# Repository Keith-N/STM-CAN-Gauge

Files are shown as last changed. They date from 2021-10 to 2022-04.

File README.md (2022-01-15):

# STM-CAN-Gauge

An STM32F042 based CAN gauge for use with rusEFI ECUs. <br/>
CAN is configured for 500k with a base ID of 512. <br/>
Input voltage tested at 5V and 12V. <br/>

Flash 'CAN Gauge.bin' through STM32CubeProgrammer using STLink and TC2030. <br/>

The only required connections for operation are supply voltage/ground and CAN High/Low. <br/>

GaugeC_Front
GaugeC_Back

Pinout from the back of connector.
Pinout

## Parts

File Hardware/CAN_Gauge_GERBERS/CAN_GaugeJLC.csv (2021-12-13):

Comment | Designator | Footprint | LCSC
120u | C11 | Capacitor_SMD:C_1206_3216Metric | C15008
2.2u | C16,C18 | Capacitor_SMD:C_0402_1005Metric | C170151
0.1u | C1,C3,C5,C13 | Capacitor_SMD:C_0402_1005Metric | C1525
1u | C2,C4,C14,C15,C17 | Capacitor_SMD:C_0402_1005Metric | C389008
10u | C9,C10 | Inductor_SMD:L_1206_3216Metric | C13585
LED | D1,D2,D3,D4,D5,D6,D7,D8,D9,D10,D11 | LED_SMD:LED_0603_1608Metric | C2286
1N5817 | D12 | Diode_SMD:D_SOD-123 | C727113
SS16HE3_B/I | D21 | Diode_SMD:D_SMA | C211772
SMBJ16CD-M3/H | D22 | Diode_SMD:D_SMB | C8830
MountingHole | H1,H2,H3,H4 | MountingHole:MountingHole_2mm
Conn_02x03_Odd_Even | J1 | Connector:Tag-Connect_TC2030-IDC-NL_2x03_P1.27mm_Vertical
Conn_01x08 | J2 | Connector_Molex:Molex_Micro-Fit_3.0_43045-0812_2x04_P3.00mm_Vertical
SolderJumper_2_Open | JP1,JP2,JP3 | Jumper:SolderJumper-2_P1.3mm_Open_Pad1.0x1.5mm
100uH | L1 | Inductor_SMD:L_0805_2012Metric | C68035
30 | L2 | Inductor_SMD:L_0402_1005Metric | C76886
10k | R1,R3,R10,R11,R12,R13,R14,R15,R24,R25,R26 | Resistor_SMD:R_0402_1005Metric | C25744
120 | R20 | Resistor_SMD:R_0402_1005Metric | C60310
1k | R2,R7,R8,R9,R16,R17,R18,R19,R21,R29,R30 | Resistor_SMD:R_0402_1005Metric | C11702
SW_Push | SW1 | Button_Switch_SMD:SW_Push_1P1T_NO_6x6mm_H9.5mm | C480275
TestPoint | TP1,TP2,TP3,TP4,TP5,TP6,TP7,TP8 | TestPoint:TestPoint_Pad_D1.0mm
STM32F042K6Tx | U1 | Package_QFP:LQFP-32_7x7mm_P0.8mm
SN65HVD230 | U2 | Package_SO:SOIC-8_3.9x4.9mm_P1.27mm | C12084
2594 | U3 | Package_SO:SOIC-8_3.9x4.9mm_P1.27mm | C316691
UG-2864HSWEG01 | U4 | custom:SSH1106_Bottom

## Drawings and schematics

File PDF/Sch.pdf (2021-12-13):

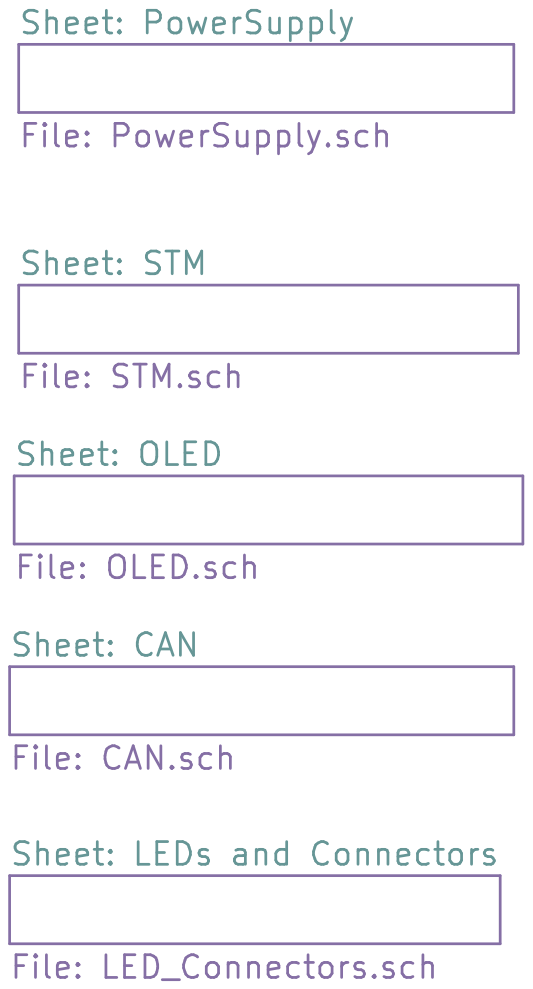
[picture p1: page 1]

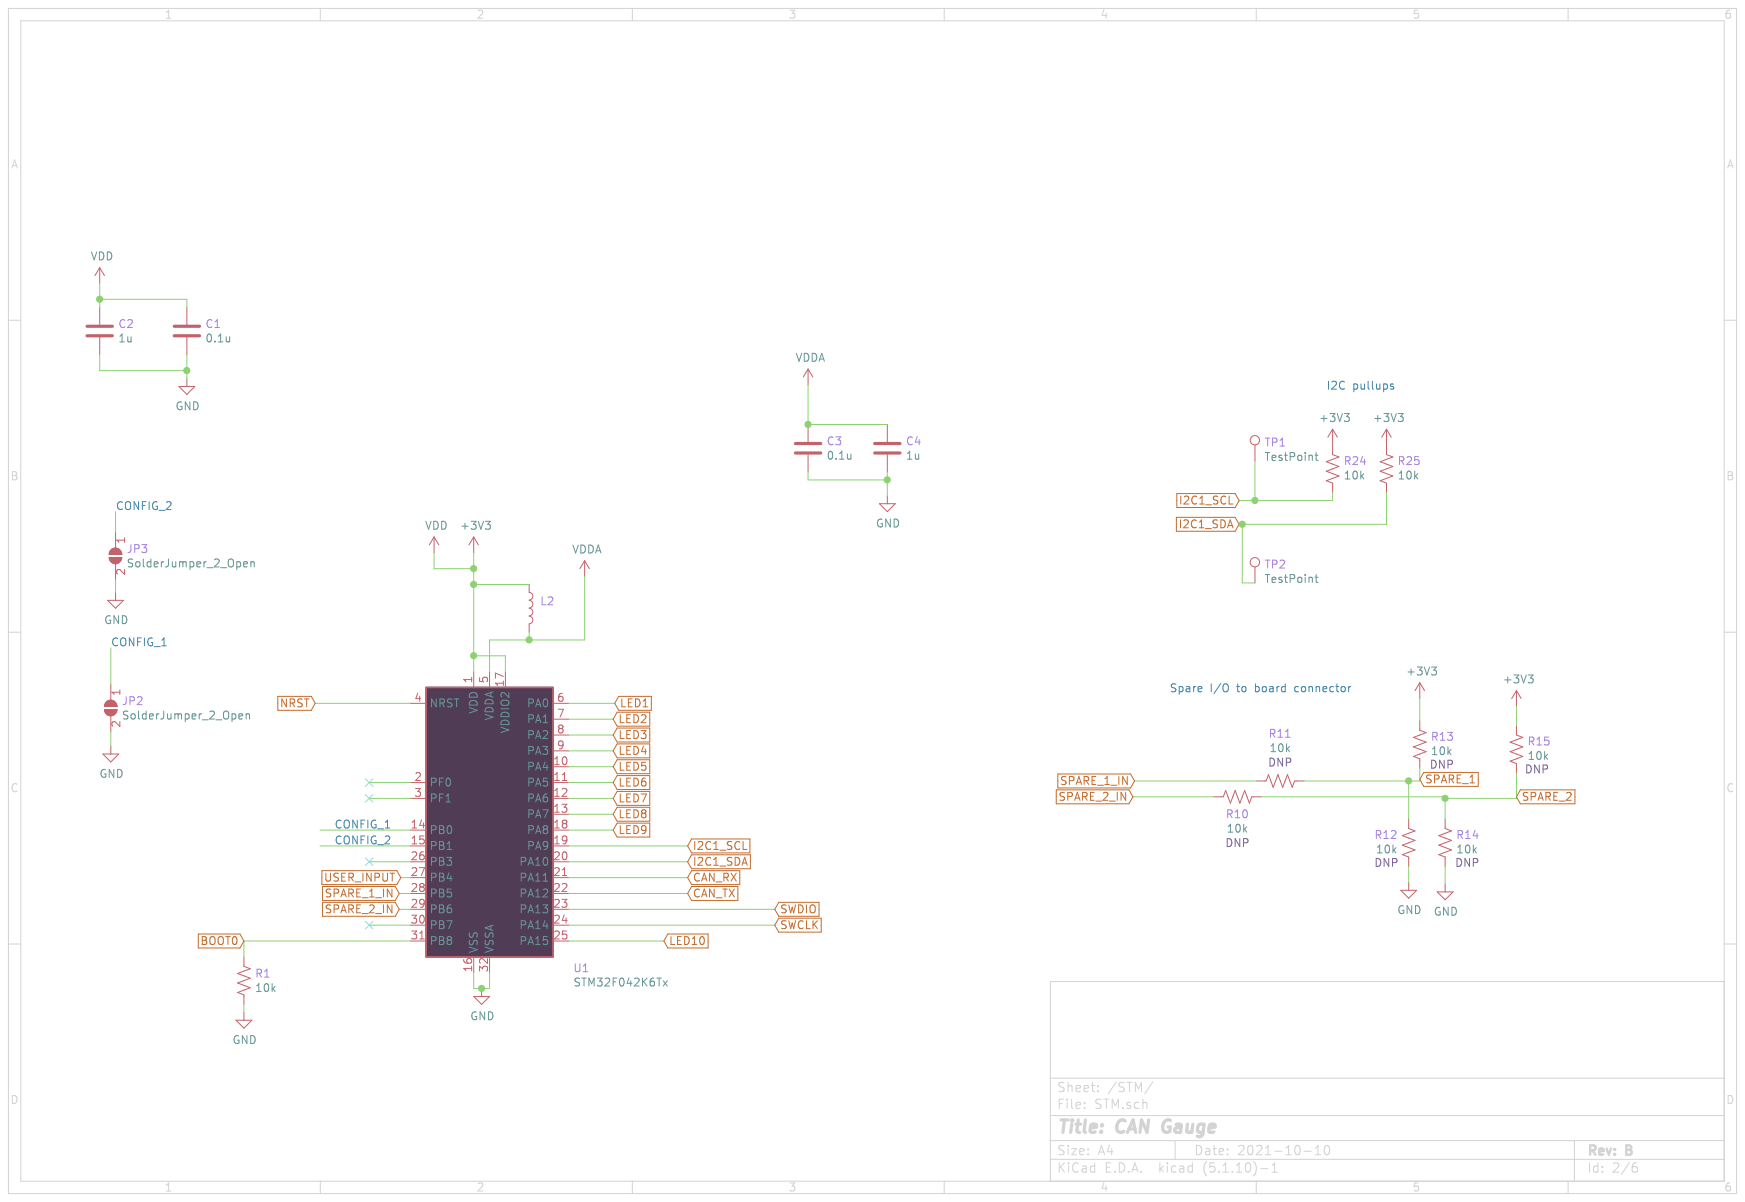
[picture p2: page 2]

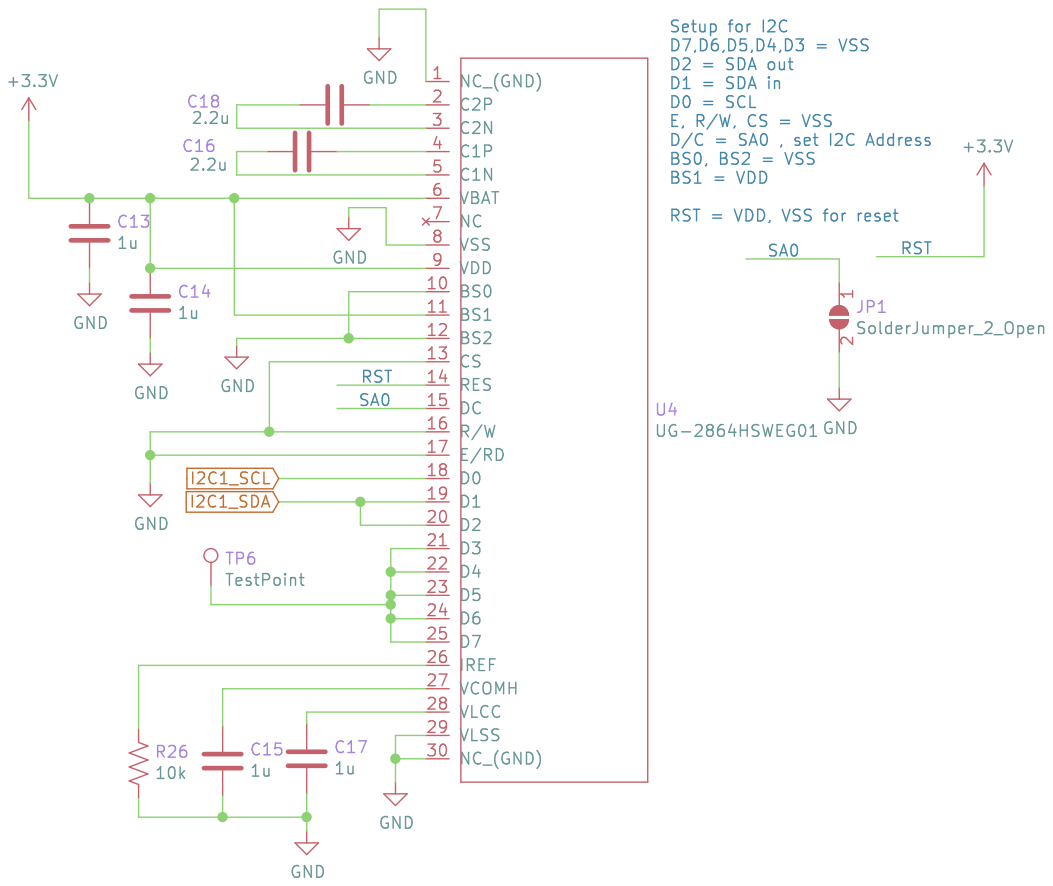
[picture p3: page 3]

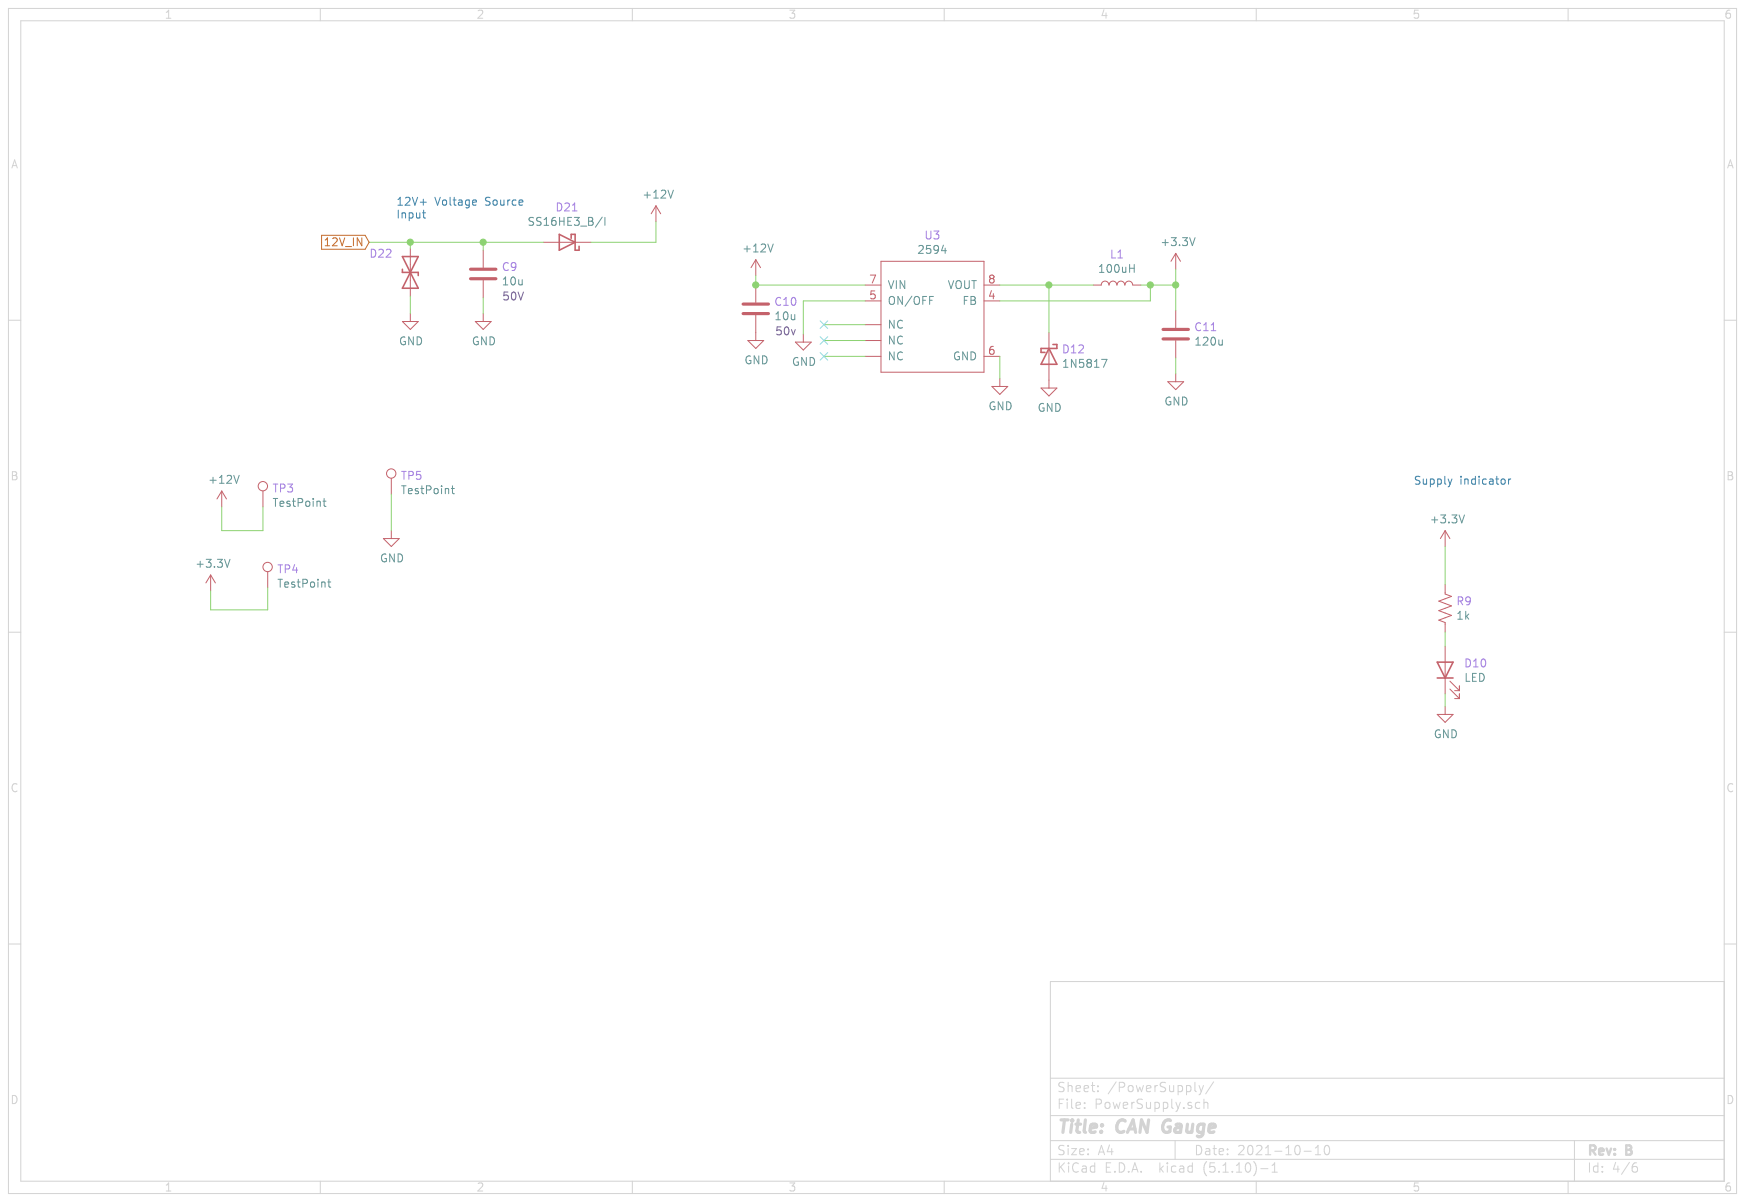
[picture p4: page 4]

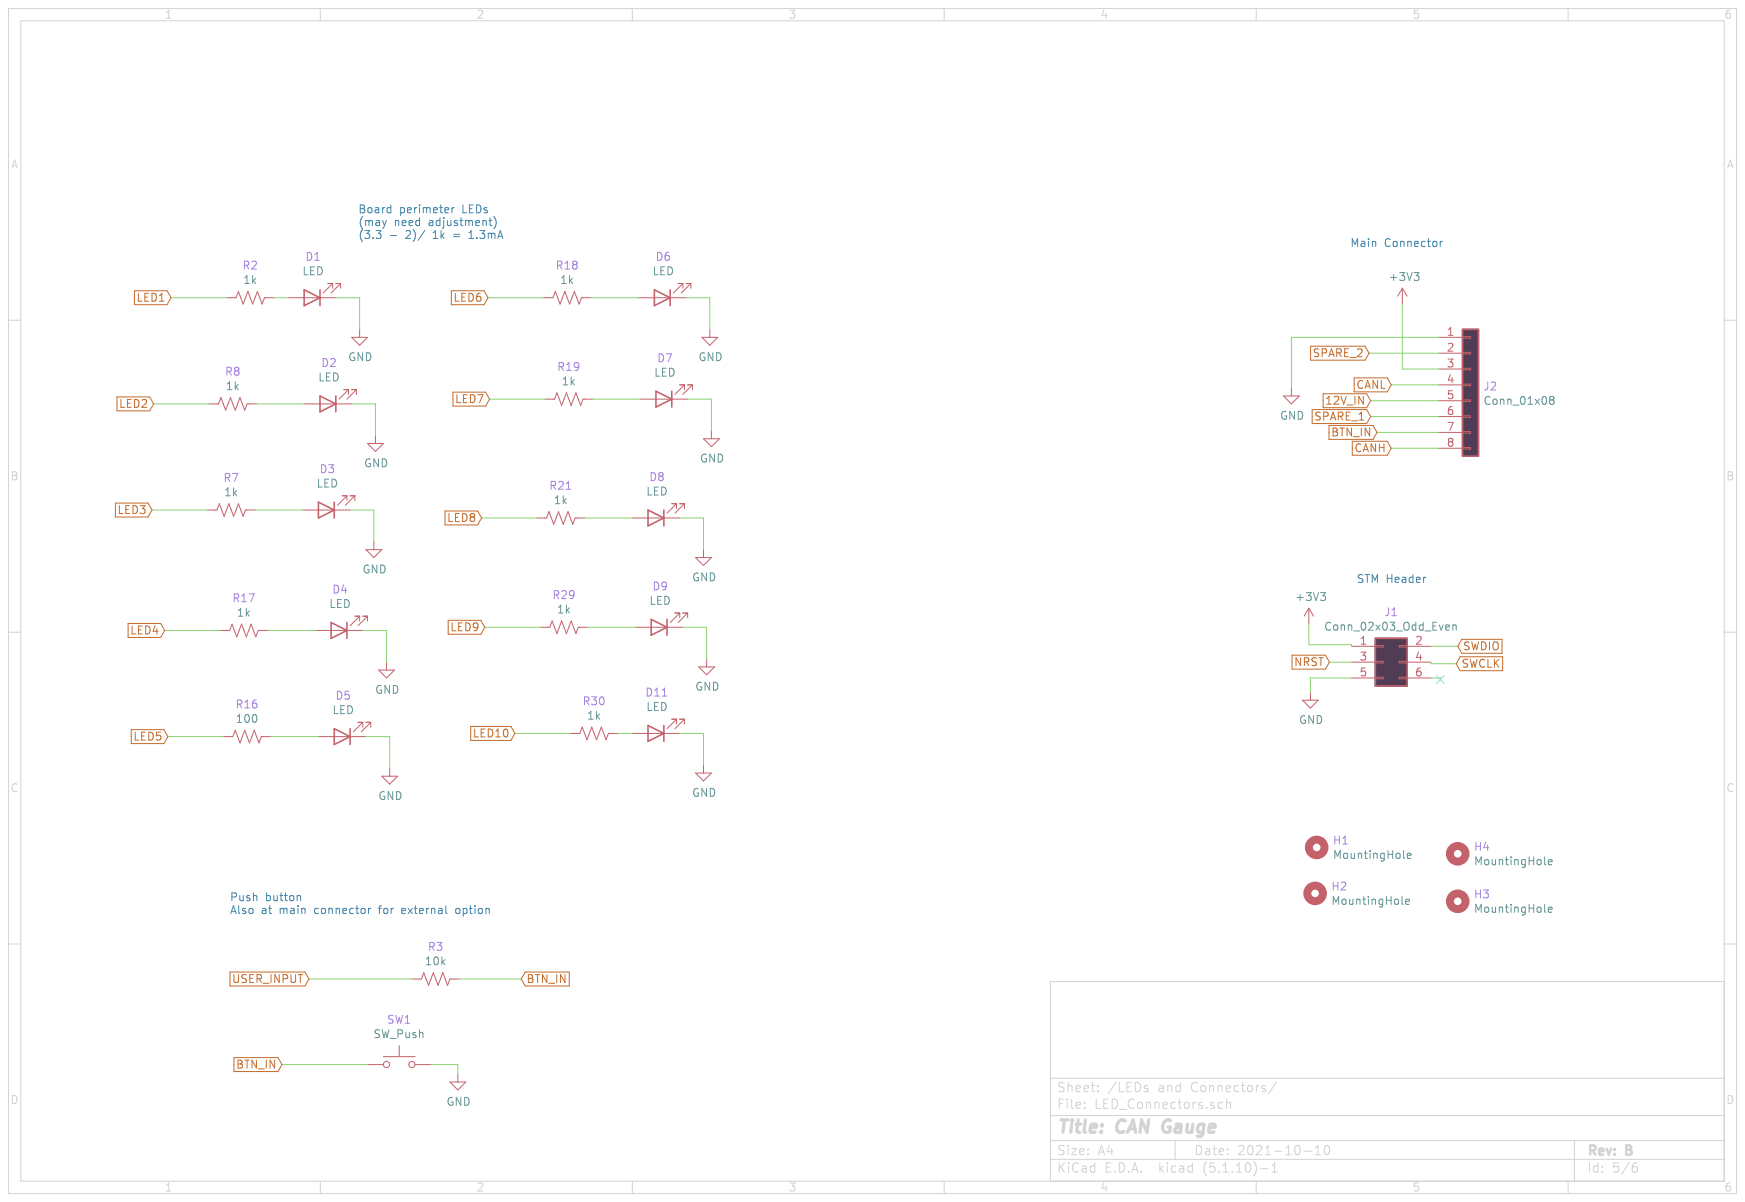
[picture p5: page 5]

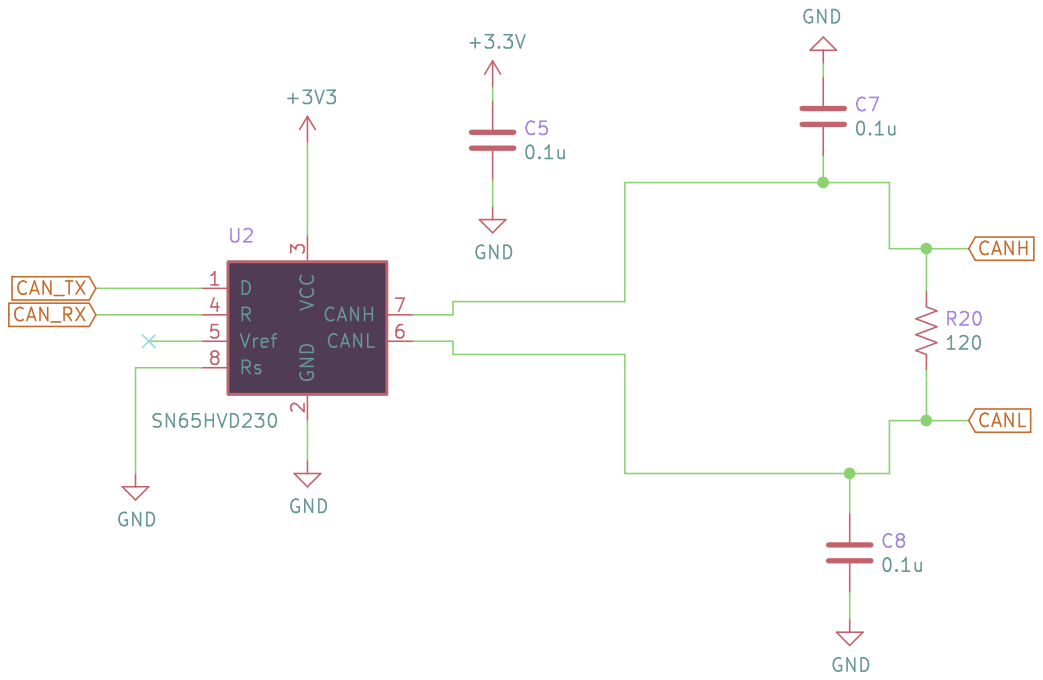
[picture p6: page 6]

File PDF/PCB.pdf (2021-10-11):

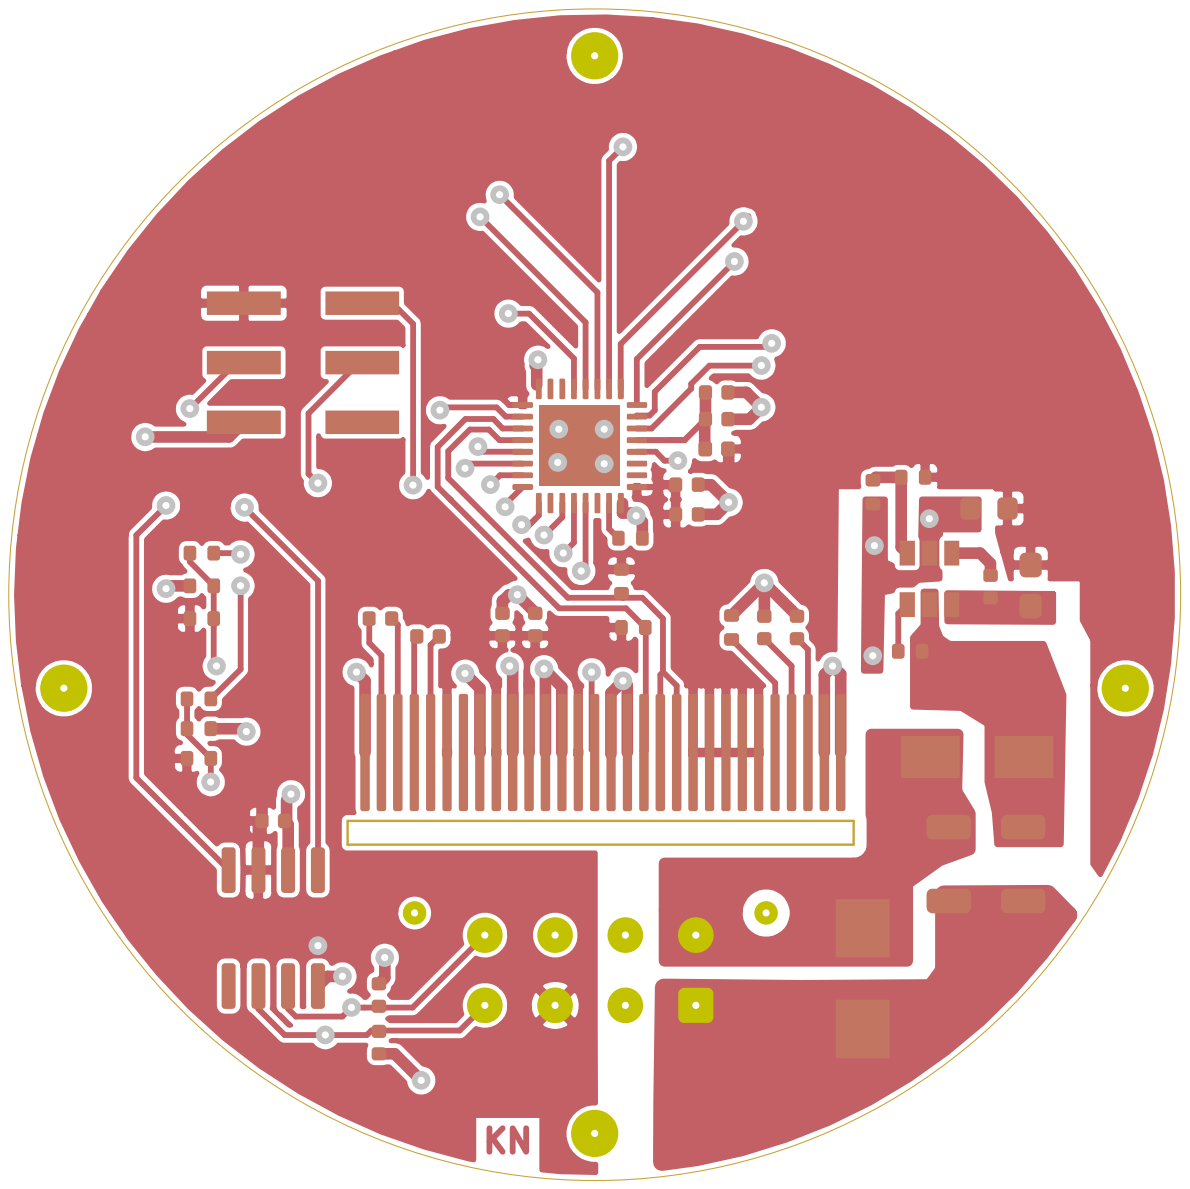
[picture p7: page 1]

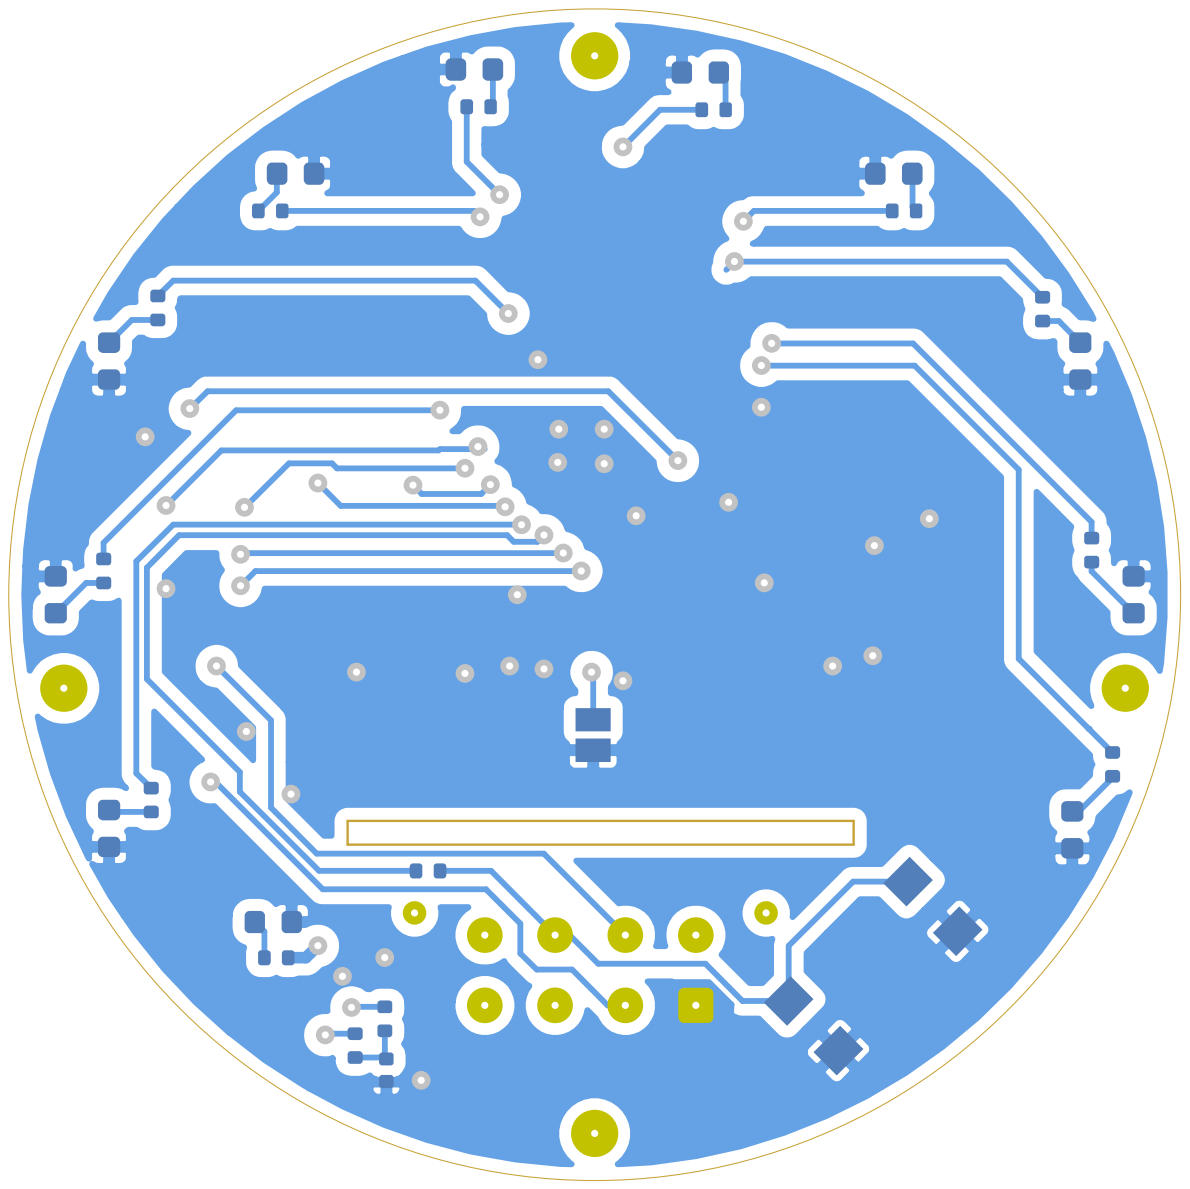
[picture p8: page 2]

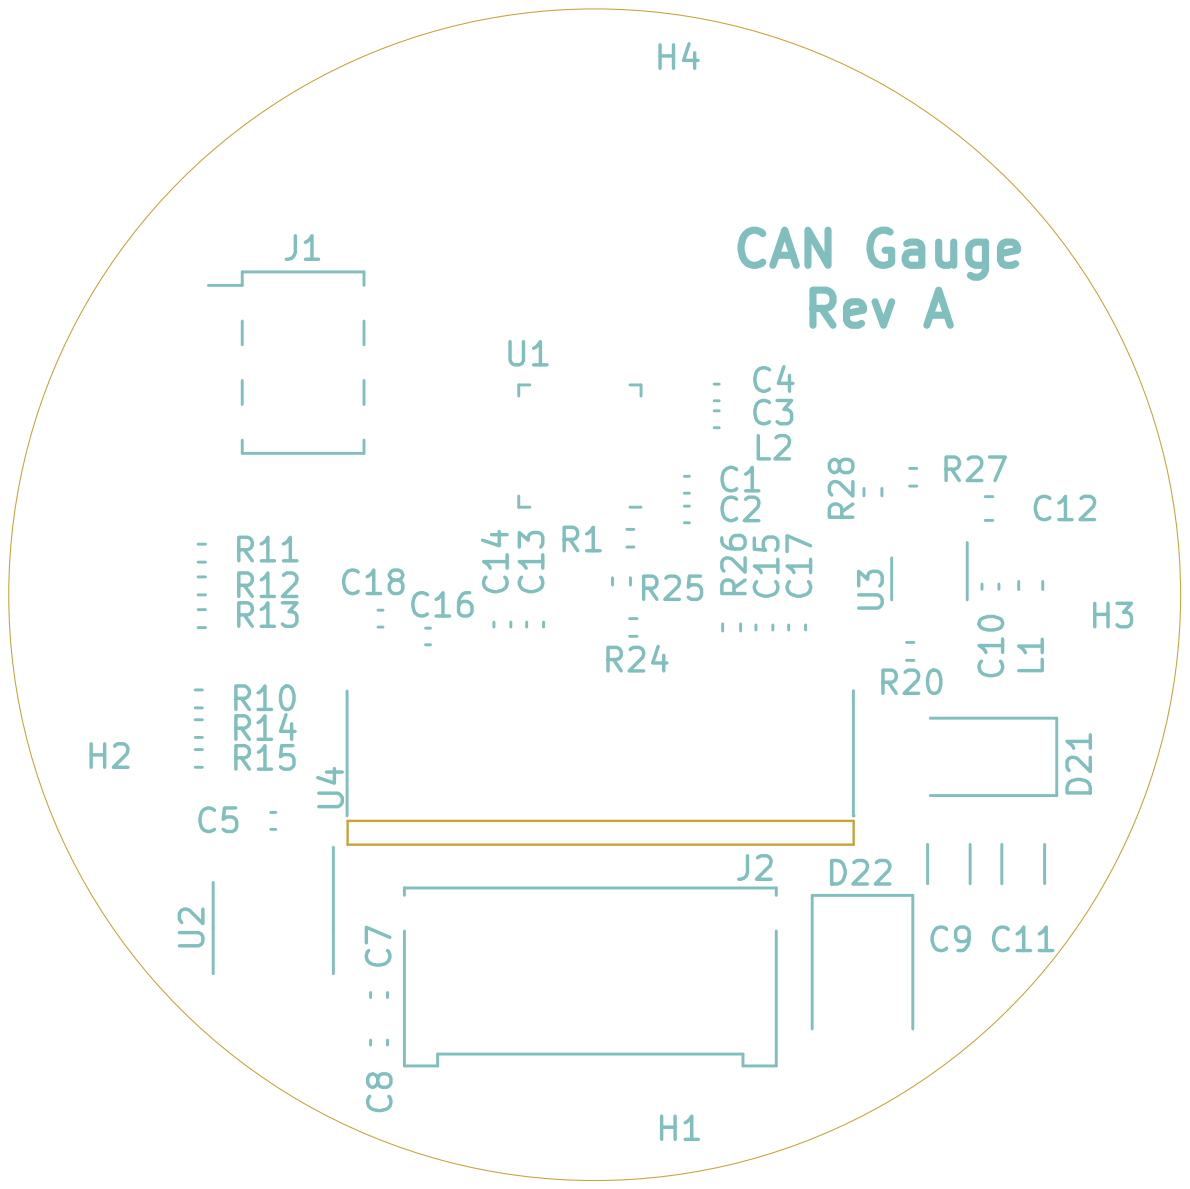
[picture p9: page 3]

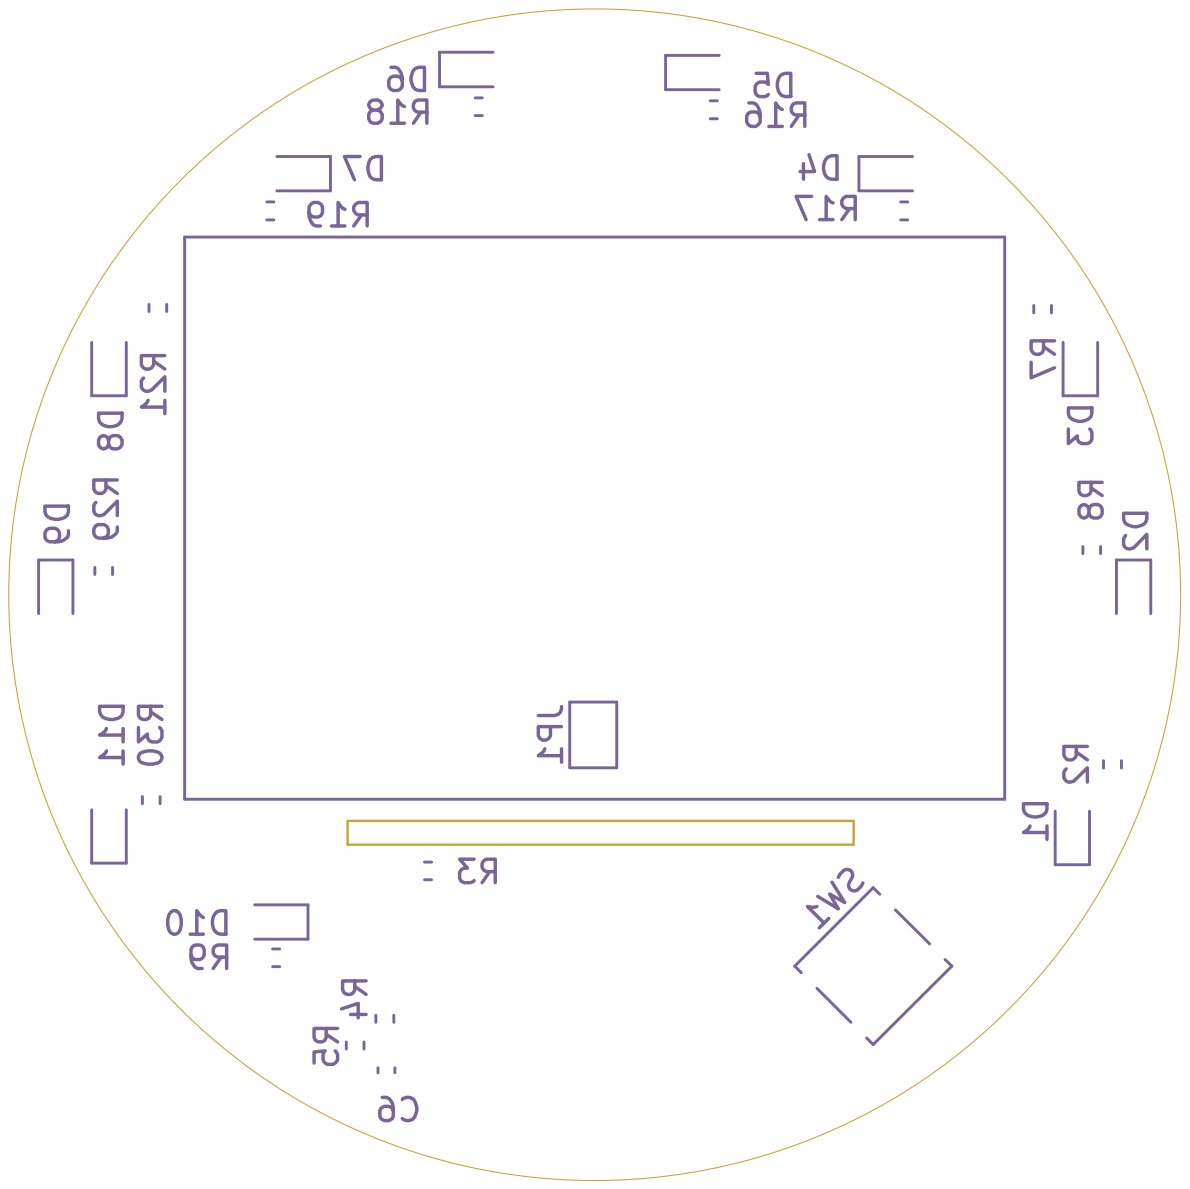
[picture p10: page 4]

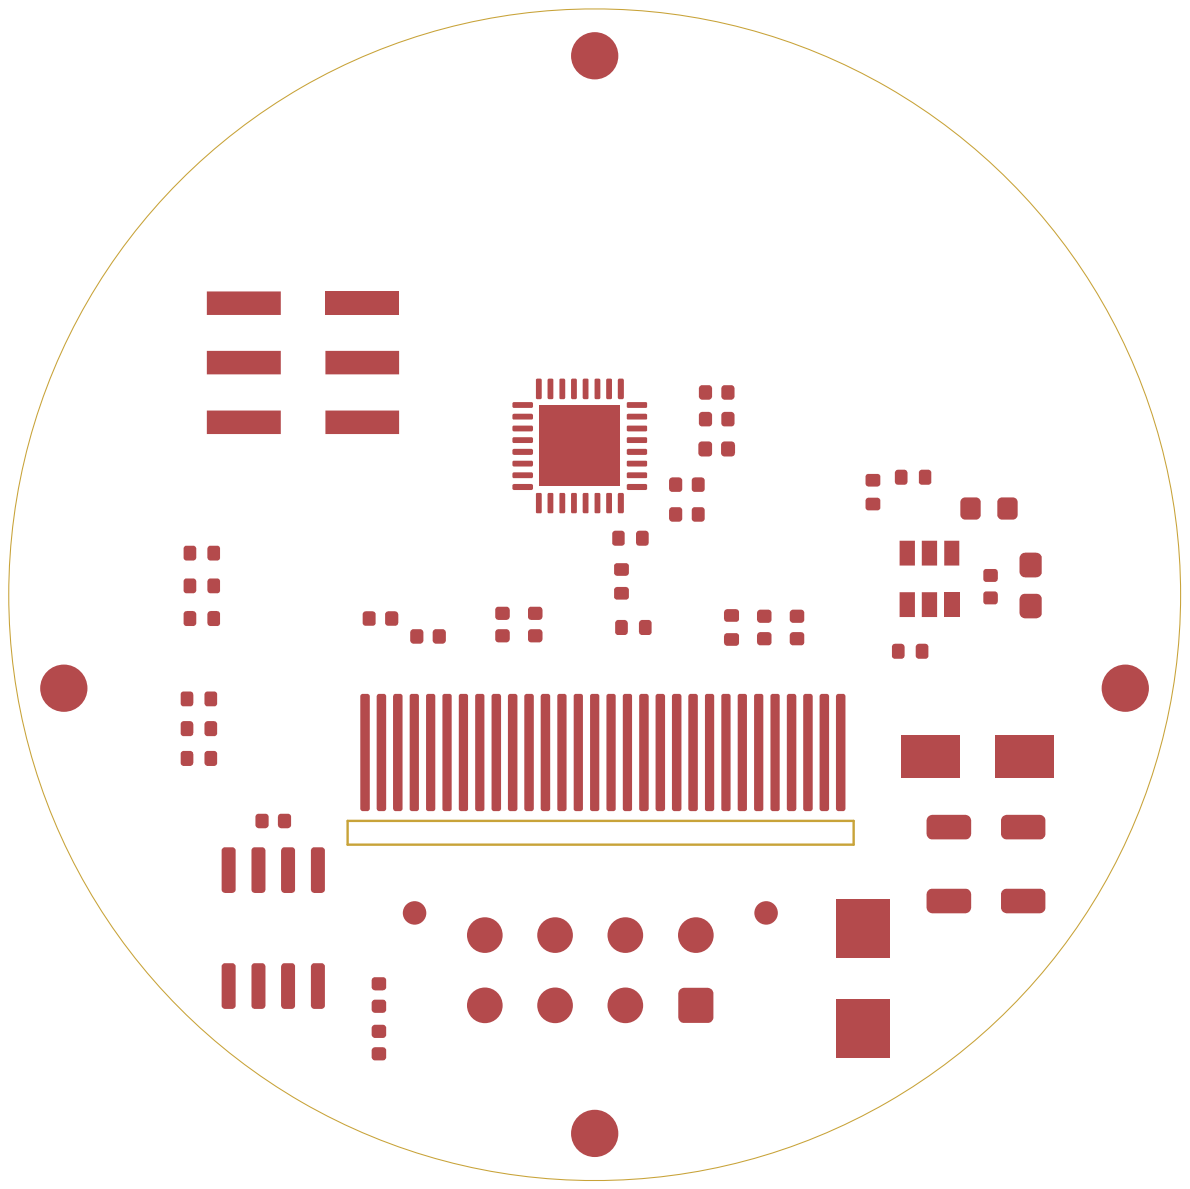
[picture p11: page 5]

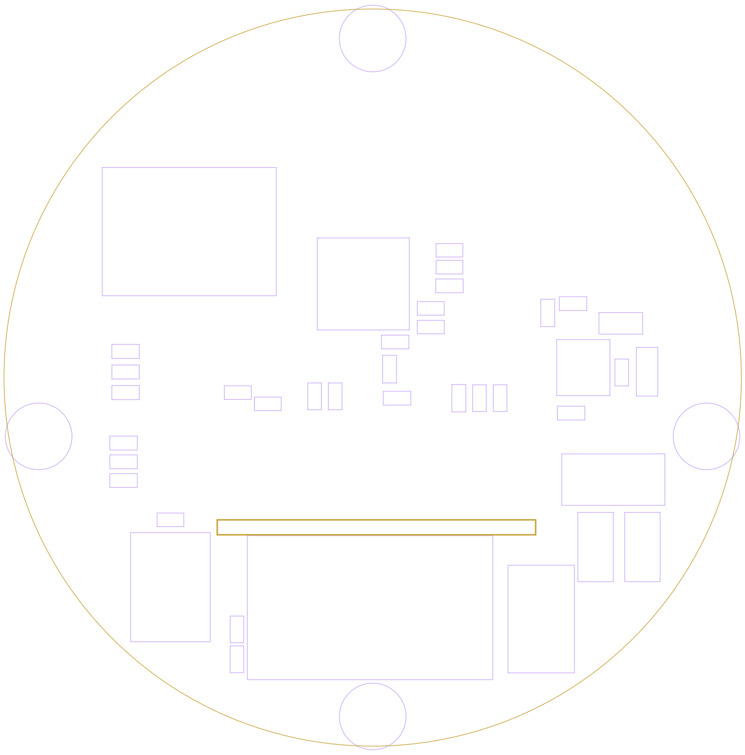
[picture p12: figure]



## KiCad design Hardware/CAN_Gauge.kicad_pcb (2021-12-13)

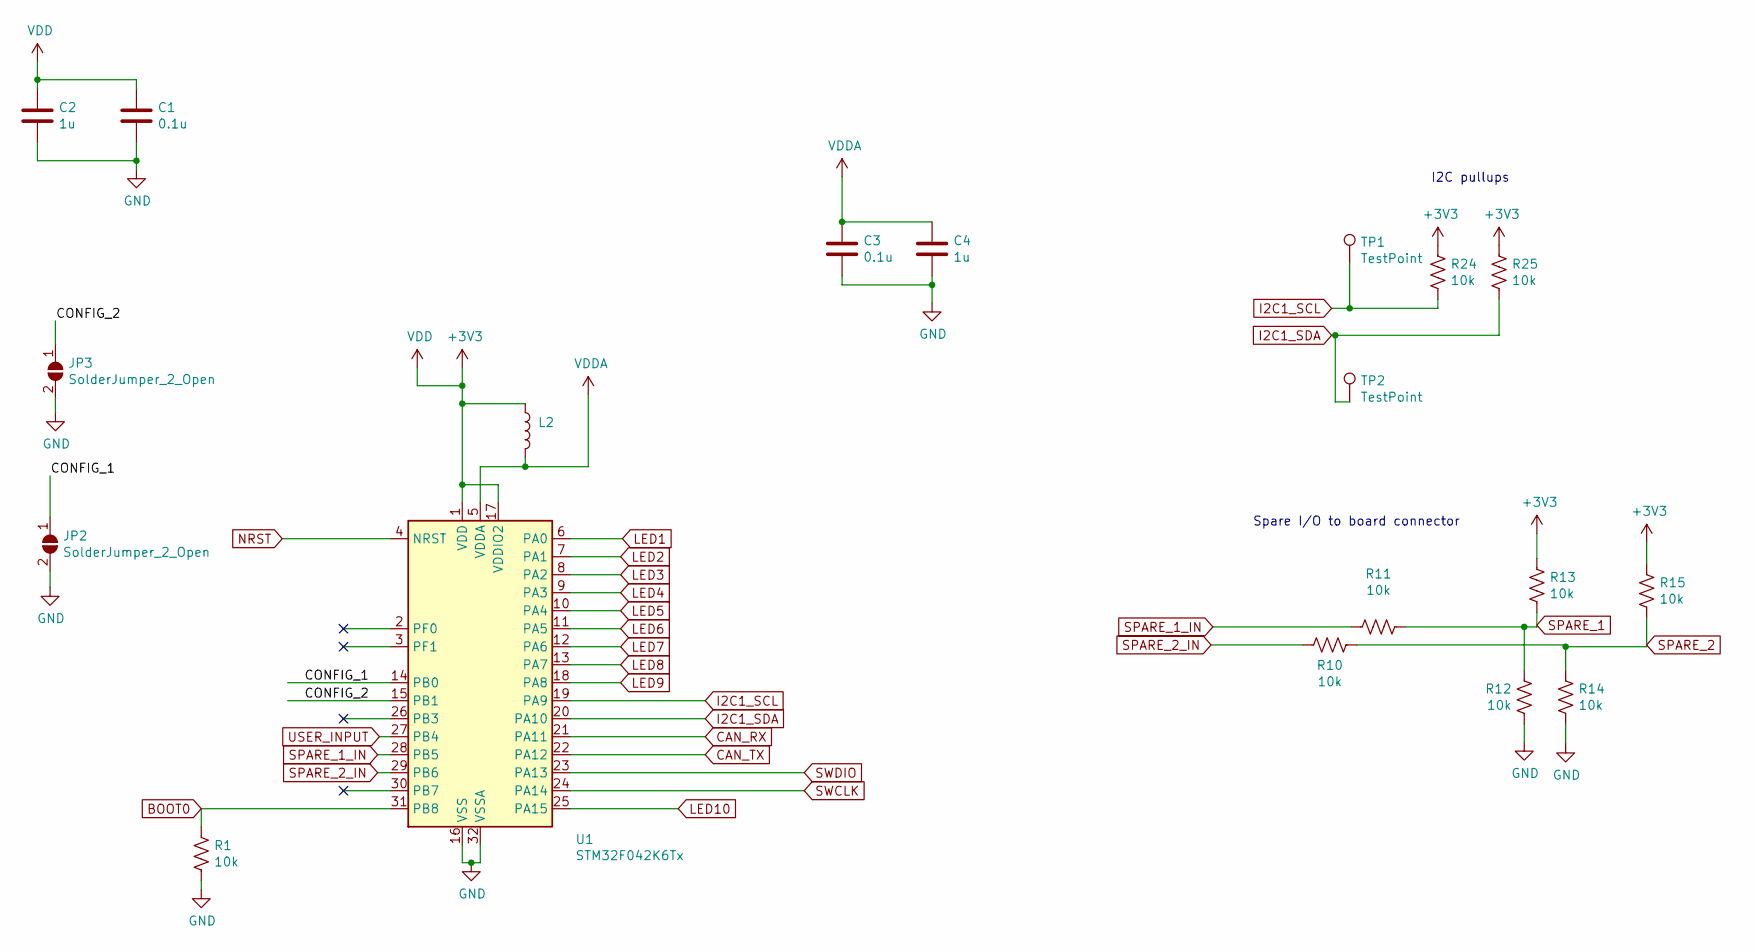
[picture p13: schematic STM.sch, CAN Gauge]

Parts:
C1, C3: 0.1u; C_0402_1005Metric; LCSC C2655418
C2, C4: 1u; C_0402_1005Metric; LCSC C389008
JP2, JP3: SolderJumper_2_Open; SolderJumper-2_P1.3mm_Open_Pad1.0x1.5mm
L2: 30; L_0402_1005Metric; LCSC C76886
R1, R10, R11, R12, R13, R14, R15, R24, R25: 10k; R_0402_1005Metric
TP1, TP2: TestPoint; TestPoint_Pad_D1.0mm
U1: STM32F042K6Tx; LQFP-32_7x7mm_P0.8mm

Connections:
/STM/CONFIG_1: JP2.1 (A), U1.14 (PB0)
/STM/CONFIG_2: JP3.1 (A), U1.15 (PB1)
BOOT0: R1.1, U1.31 (PB8)
CAN_RX: U1.21 (PA11); also elsewhere on the board
CAN_TX: U1.22 (PA12); also elsewhere on the board
GND: C1.2, C2.2, C3.2, C4.2, JP2.2 (B), JP3.2 (B), R1.2, R12.1, R14.1, U1.16 (VSS), U1.32 (VSSA); also elsewhere on the board
I2C1_SCL: R24.1, TP1.1, U1.19 (PA9); also elsewhere on the board
I2C1_SDA: R25.1, TP2.1, U1.20 (PA10); also elsewhere on the board
LED1: U1.6 (PA0); also elsewhere on the board
LED2: U1.7 (PA1); also elsewhere on the board
LED3: U1.8 (PA2); also elsewhere on the board
LED4: U1.9 (PA3); also elsewhere on the board
LED5: U1.10 (PA4); also elsewhere on the board
LED6: U1.11 (PA5); also elsewhere on the board
LED7: U1.12 (PA6); also elsewhere on the board
LED8: U1.13 (PA7); also elsewhere on the board
LED9: U1.18 (PA8); also elsewhere on the board
LED10: U1.25 (PA15); also elsewhere on the board
NRST: U1.4 (NRST); also elsewhere on the board
SPARE_1: R11.2, R12.2, R13.1; also elsewhere on the board
SPARE_1_IN: R11.1, U1.28 (PB5)
SPARE_2: R10.2, R14.2, R15.1; also elsewhere on the board
SPARE_2_IN: R10.1, U1.29 (PB6)
SWCLK: U1.24 (PA14); also elsewhere on the board
SWDIO: U1.23 (PA13); also elsewhere on the board
USER_INPUT: U1.27 (PB4); also elsewhere on the board
VDDA: C3.1, C4.1, L2.2, U1.5 (VDDA)

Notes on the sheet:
I2C pullups
Spare I/O to board connector

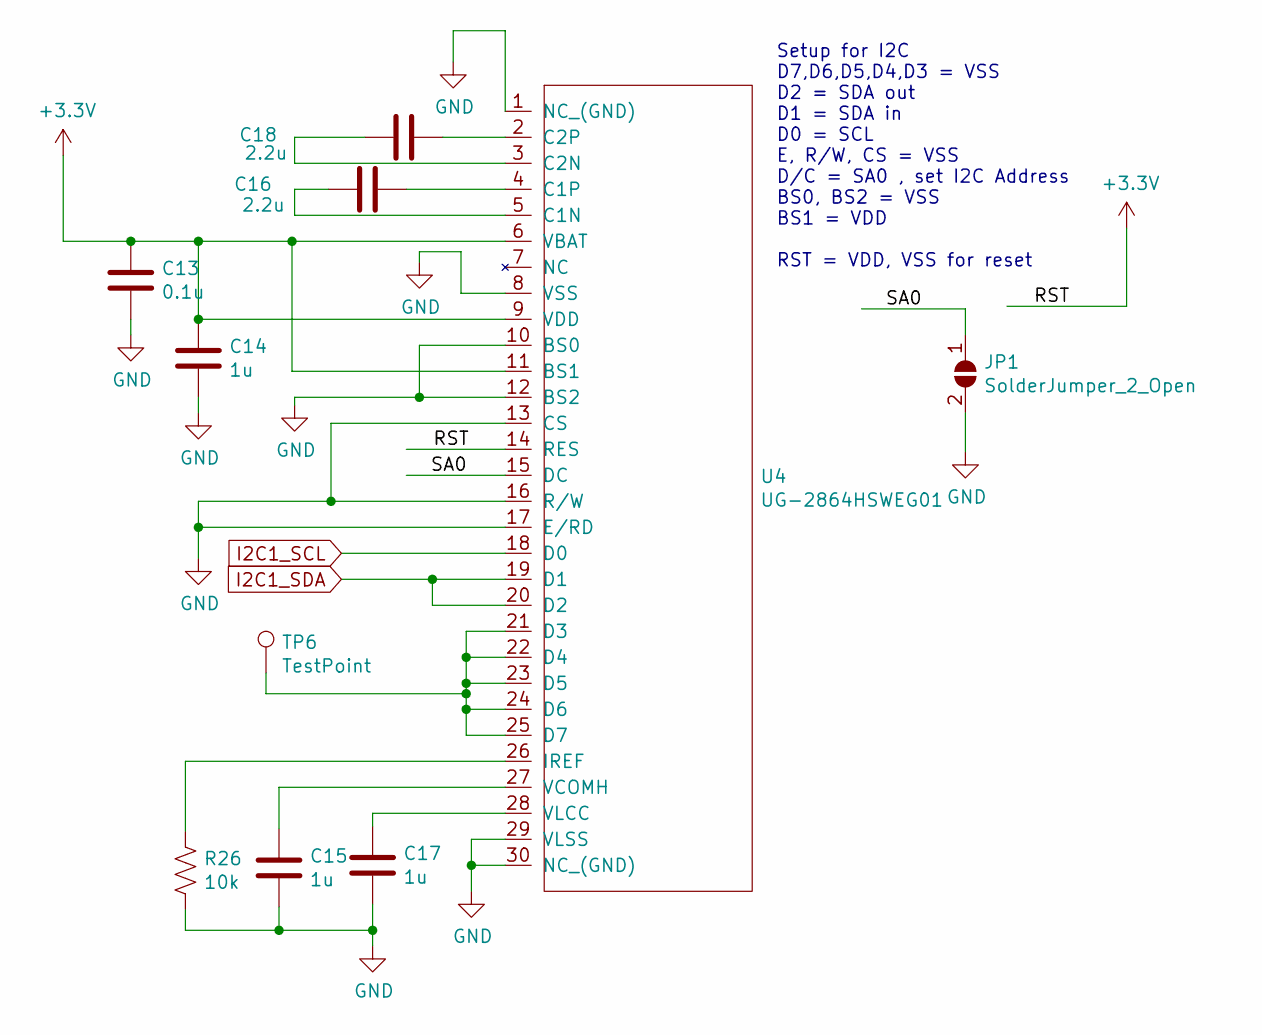
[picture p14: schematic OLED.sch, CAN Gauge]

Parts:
C13: 0.1u; C_0402_1005Metric; LCSC C1525
C14, C15, C17: 1u; C_0402_1005Metric; LCSC C52923
C16, C18: 2.2u; C_0402_1005Metric; LCSC C170151
JP1: SolderJumper_2_Open; SolderJumper-2_P1.3mm_Open_Pad1.0x1.5mm
R26: 10k; R_0402_1005Metric; LCSC C25744
TP6: TestPoint; TestPoint_Pad_D1.0mm
U4: UG-2864HSWEG01; SSH1106_Bottom

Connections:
/OLED/SA0: JP1.1 (A), U4.15 (DC)
GND: C13.1, C14.1, C15.1, C17.1, JP1.2 (B), R26.1, U4.1 (NC_(GND)), U4.8 (VSS), U4.10 (BS0), U4.12 (BS2), U4.13 (CS), U4.16 (R/W), U4.17 (E/RD), U4.29 (VLSS), U4.30 (NC_(GND)); also elsewhere on the board
I2C1_SCL: U4.18 (D0); also elsewhere on the board
I2C1_SDA: U4.19 (D1), U4.20 (D2); also elsewhere on the board
unnamed: C15.2, U4.27 (VCOMH)
unnamed: C16.1, U4.5 (C1N)
unnamed: C16.2, U4.4 (C1P)
unnamed: C17.2, U4.28 (VLCC)
unnamed: C18.1, U4.3 (C2N)
unnamed: C18.2, U4.2 (C2P)
unnamed: R26.2, U4.26 (IREF)
unnamed: TP6.1, U4.21 (D3), U4.22 (D4), U4.23 (D5), U4.24 (D6), U4.25 (D7)

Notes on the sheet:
Setup for I2C D7,D6,D5,D4,D3 = VSS D2 = SDA out D1 = SDA in D0 = SCL E, R/W, CS = VSS D/C = SA0 , set I2C Address BS0, BS2 = VSS BS1 = VDD RST = VDD, VSS for reset

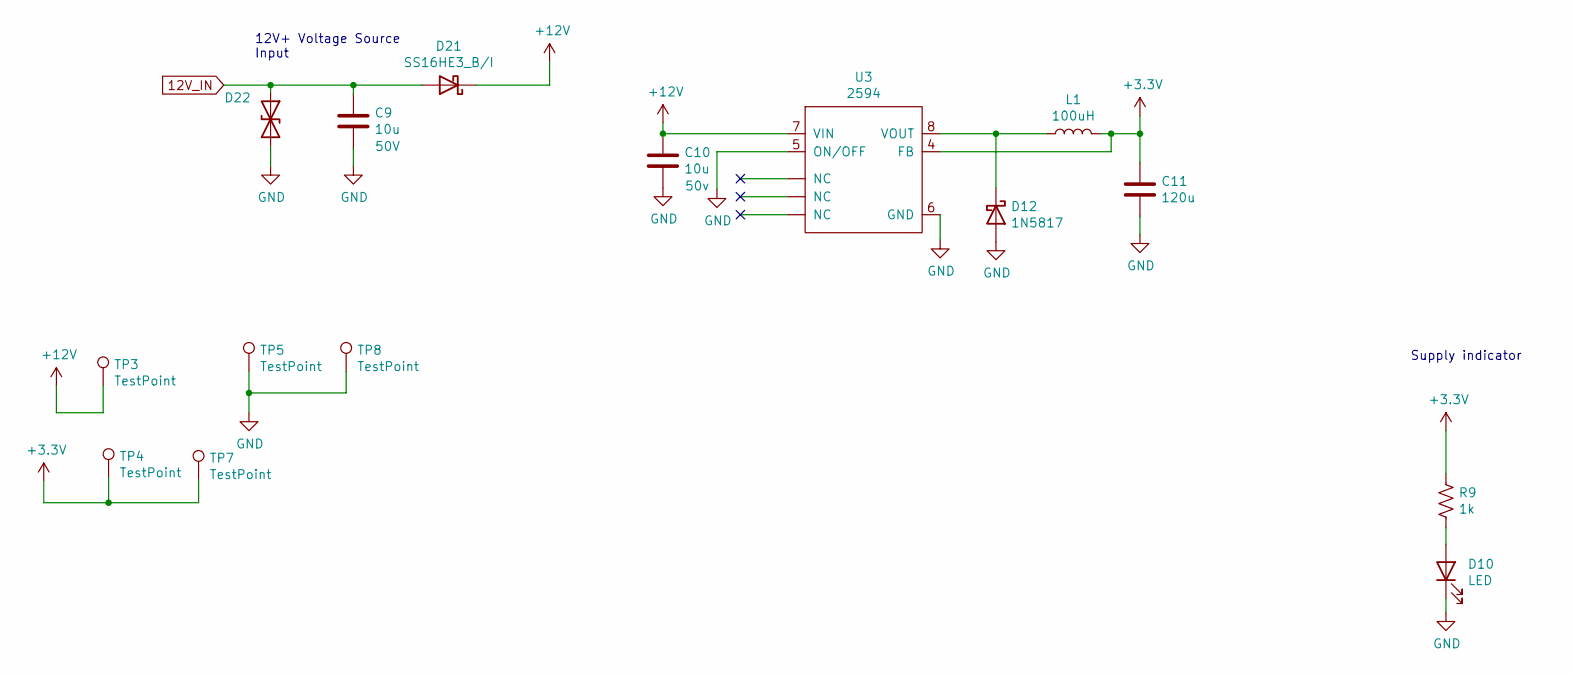
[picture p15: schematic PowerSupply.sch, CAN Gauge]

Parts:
C9: 10u; L_1206_3216Metric; Voltage 50V; Part Number CL31A106MBHNNNE; LCSC C13585
C10: 10u; L_1206_3216Metric; Voltage 50v
C11: 120u; C_1206_3216Metric; LCSC C15008
D10: LED; LED_0603_1608Metric; LCSC C2286
D12: 1N5817; D_SOD-123
D21: SS16HE3_B/I; D_SMA; Part Number SS16HE3_B/I; LCSC C211772
D22: SMBJ16CD-M3/H; D_SMB; Part Number SMBJ16CD-M3/H; LCSC C8830
L1: 100uH; L_0805_2012Metric; LCSC C68035
R9: 1k; R_0402_1005Metric; LCSC C11702
TP3, TP4, TP5, TP7, TP8: TestPoint; TestPoint_Pad_D1.0mm
U3: 2594; SOIC-8_3.9x4.9mm_P1.27mm; LCSC C316691

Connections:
12V_IN: C9.1, D21.2 (A), D22.1 (A1); also elsewhere on the board
+12V: C10.1, D21.1 (K), TP3.1, U3.7 (VIN)
GND: C9.2, C10.2, C11.2, D10.1 (K), D12.2 (A), D22.2 (A2), TP5.1, TP8.1, U3.5 (ON/OFF), U3.6 (GND); also elsewhere on the board
unnamed: D10.2 (A), R9.2
unnamed: D12.1 (K), L1.1, U3.8 (VOUT)

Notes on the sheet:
12V+ Voltage Source Input
Supply indicator

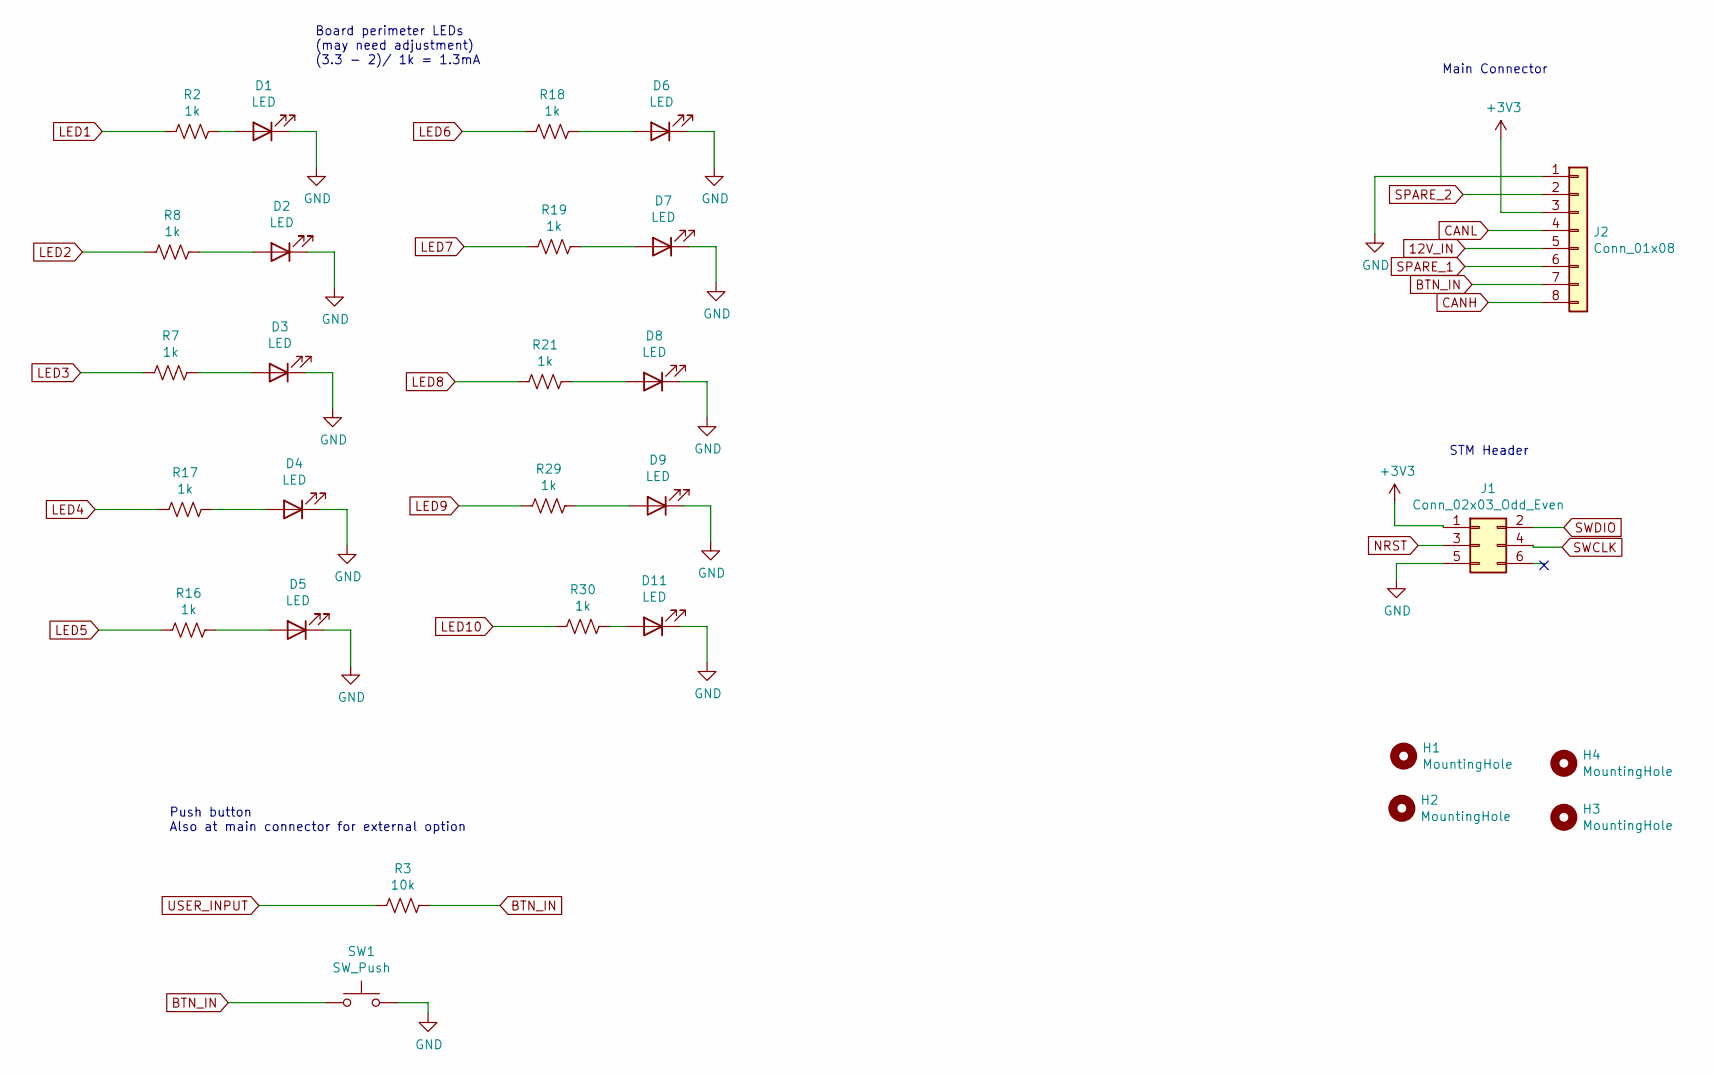
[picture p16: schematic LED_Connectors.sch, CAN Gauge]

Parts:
D1, D2, D3, D4, D5, D6, D7, D8, D9, D11: LED; LED_0603_1608Metric
H1, H2, H3, H4: MountingHole; MountingHole_2mm
J1: Conn_02x03_Odd_Even; Tag-Connect_TC2030-IDC-NL_2x03_P1.27mm_Vertical
J2: Conn_01x08; Molex_Micro-Fit_3.0_43045-0812_2x04_P3.00mm_Vertical
R2, R7, R8, R16, R17, R18, R19, R21, R29, R30: 1k; R_0402_1005Metric
R3: 10k; R_0402_1005Metric; LCSC C60489
SW1: SW_Push; SW_Push_1P1T_NO_6x6mm_H9.5mm; LCSC C480275

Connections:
12V_IN: J2.5; also elsewhere on the board
BTN_IN: J2.7, R3.1, SW1.1
CANH: J2.8; also elsewhere on the board
CANL: J2.4; also elsewhere on the board
GND: D1.1 (K), D2.1 (K), D3.1 (K), D4.1 (K), D5.1 (K), D6.1 (K), D7.1 (K), D8.1 (K), D9.1 (K), D11.1 (K), J1.5, J2.1, SW1.2; also elsewhere on the board
LED1: R2.2; also elsewhere on the board
LED2: R8.2; also elsewhere on the board
LED3: R7.2; also elsewhere on the board
LED4: R17.2; also elsewhere on the board
LED5: R16.2; also elsewhere on the board
LED6: R18.2; also elsewhere on the board
LED7: R19.2; also elsewhere on the board
LED8: R21.2; also elsewhere on the board
LED9: R29.2; also elsewhere on the board
LED10: R30.2; also elsewhere on the board
NRST: J1.3; also elsewhere on the board
unnamed: D1.2 (A), R2.1
unnamed: D2.2 (A), R8.1
unnamed: D3.2 (A), R7.1
unnamed: D4.2 (A), R17.1
unnamed: D5.2 (A), R16.1
unnamed: D6.2 (A), R18.1
unnamed: D7.2 (A), R19.1
unnamed: D8.2 (A), R21.1
unnamed: D9.2 (A), R29.1
unnamed: D11.2 (A), R30.1
SPARE_1: J2.6; also elsewhere on the board
SPARE_2: J2.2; also elsewhere on the board
SWCLK: J1.4; also elsewhere on the board
SWDIO: J1.2; also elsewhere on the board
USER_INPUT: R3.2; also elsewhere on the board

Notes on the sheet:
Board perimeter LEDs (may need adjustment) (3.3 - 2)/ 1k = 1.3mA
STM Header
Main Connector
Push button Also at main connector for external option

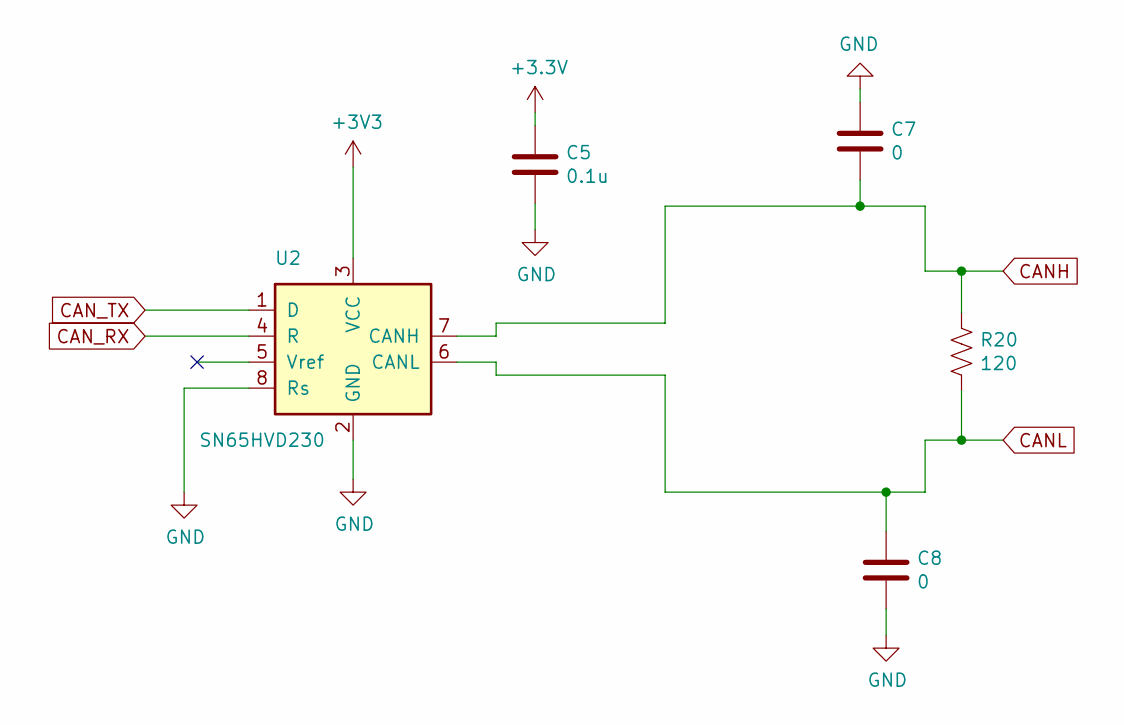
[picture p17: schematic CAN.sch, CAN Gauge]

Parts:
C5: 0.1u; C_0402_1005Metric
C7, C8: 0; C_0402_1005Metric
R20: 120; R_0402_1005Metric; LCSC C60310
U2: SN65HVD230; SOIC-8_3.9x4.9mm_P1.27mm; LCSC C12084

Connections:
CANH: C7.2, R20.1, U2.7 (CANH); also elsewhere on the board
CANL: C8.1, R20.2, U2.6 (CANL); also elsewhere on the board
CAN_RX: U2.4 (R); also elsewhere on the board
CAN_TX: U2.1 (D); also elsewhere on the board
GND: C5.2, C7.1, C8.2, U2.2 (GND), U2.8 (Rs); also elsewhere on the board

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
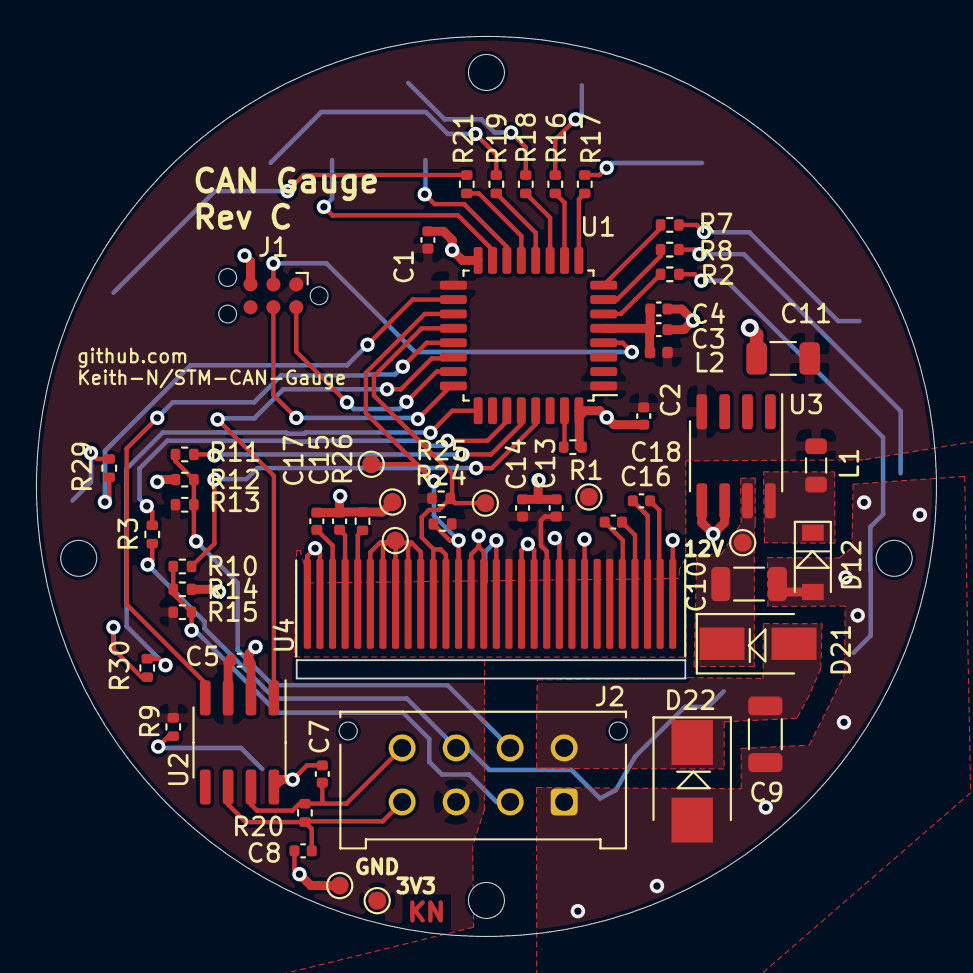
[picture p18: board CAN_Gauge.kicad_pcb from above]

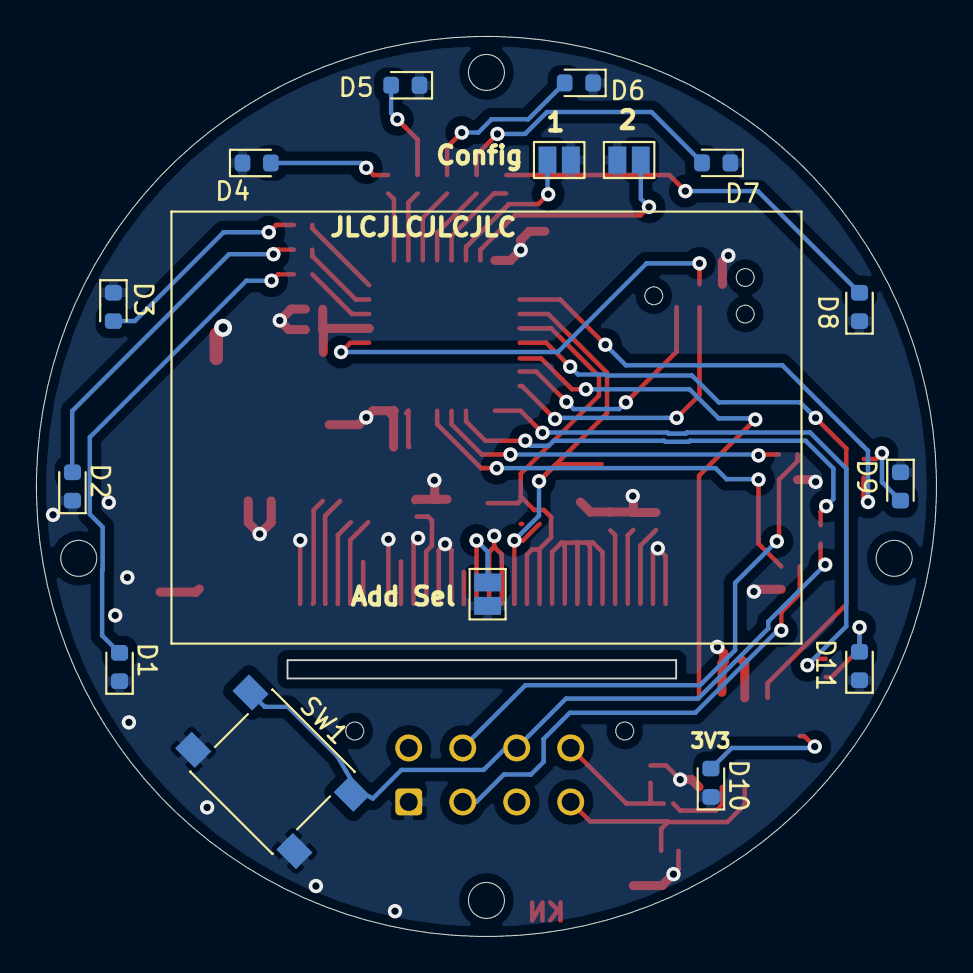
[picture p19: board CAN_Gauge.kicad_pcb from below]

Board: 2 copper layers, 50.0 x 50.0 mm, 77 parts (15 on the bottom side), 54 nets.

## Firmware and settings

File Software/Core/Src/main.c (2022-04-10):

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
/* Includes ------------------------------------------------------------------*/
#include "main.h"

/* USER CODE BEGIN Includes */
#include "ssd1306.h"
#include <stdbool.h>
#include <stdio.h>
/* USER CODE END Includes */

CAN_HandleTypeDef hcan;
I2C_HandleTypeDef hi2c1;

/* USER CODE BEGIN PV */

CAN_RxHeaderTypeDef rxHeader; 			//CAN Bus receive header
uint8_t canRX[8] = {0,0,0,0,0,0,0,0};  	//CAN Bus Receive Buffer
CAN_FilterTypeDef canfilter; 			//CAN Bus Filter


/* Define -------------------------------------------------------------*/
#define startupInfo
#define CANtimeout
#define LEDstartup
#define OLEDstartup
//#define DEBUG


/* Configuration Variables -------------------------------------------------------------*/

//Displays on startup screen
int buildDate = 220409;

// CAN
const int baseCANid = 512;
const int tempOffset = 40;

//Gauges, adjust for total # and desired starting gauge
int currentGauge = 0;
int totalNumGauge = 8;

// Time out for CAN
int canWaitTime = 2000;

// Startup initialization stuff
int startupDelay = 100;
int OLEDreinit = 10;

// User button
int currentMs = 0;
int lastMs = 0;
int btnDebounce = 250;
int btnPress = 0;


/* CAN Data -------------------------------------------------------------*/

// Format for data
// multi     -  Scaling Multiplier
// div  	 - 	Scaling Divider
// max		 -	Maximum value for LEDs
// min		 - 	value for LEDs
// ID		 -  Selects filter ID, adder from base ID
// dec       -  Use decimals? 0 for no


struct rxData{

	float multi, div, max, min;
	int ID;
	int dec;
	float scaled;
	int val;
};


// 0
int warningCount = 0;
int lastError = 0;
int revLimit = 0;
int mainRelay = 0;
int fuelPump = 0;
int CEL = 0;
int egoHeater = 0;

//[Multiplier] [Divider] [max] [min] [ID] [Decimal]

// 1					{multi	div	 	max		min		ID	  dec}
struct rxData rpm = 	{1,		1,		7000,	50,		1,		0};
struct rxData vss = 	{1,		1,		1,		180,	1,		0};
struct rxData mph = 	{62,	100,	1,		180,	1,		0};
struct rxData timing =  {1,		1,		50,		-50,	1,		0};
struct rxData injDuty = {1,		1,		100,	0,		1,		0};

// 2					{multi	div	 	max		min		ID	  dec}
struct rxData accel = 	{1,		1,		100,	0,		2,		0};
struct rxData tps1 = 	{1,		1,		100,	0,		2,		0};
struct rxData tps2 = 	{1,		1,		100,	0,		2,		0};

// 3					{multi	div		max		min		ID		dec
struct rxData map = 	{1,		30,		120,	0,		3, 		1};
struct rxData clt = 	{1,		1,		200,	0,		3,		0};
struct rxData iat = 	{1,		1,		100,	0,		3,		0};
struct rxData auxT1 = 	{1,		1,		250,	0,		3,		0};
struct rxData auxT2 = 	{1,		1,		250,	0,		3,		0};
struct rxData mcuT = 	{1,		1,		250,	0,		3,		0};
struct rxData fuel = 	{1,		1,		100,	0,		3,		0};

// 4					{multi	div		max		min		ID		dec
struct rxData afr = 	{1,		100,	18,		8,		4,		1};
struct rxData oilPress= {1,		10,		100,	0,		4,		0};
struct rxData vvtPos = 	{1,		1,		50,		-50,	4,		0};
struct rxData battery = {1,		1000,	15,		5,		4,		1};

// 5						{multi	div		max		min		ID		Dec
struct rxData cylAirMass =	{1,		1,		100,	0,		5,		0};
struct rxData estAir =		{1,		10,		100,	0,		5,		0};
struct rxData injPW = 		{1,		10,		100,	0,		5,		0};


/* Misc Variables -------------------------------------------------------------*/

// CAN IDs for Filters
const int filterID[] = {(baseCANid), (baseCANid +1), (baseCANid +2), (baseCANid +3), (baseCANid +4), (baseCANid +5)};
int currentFilter = 4;
int rxID;
int msgRXstatus = 0;
char buff[16];
int p;
int lastCanMessage = 0;
int config = 0;

/* USER CODE END PV */

void SystemClock_Config(void);
static void MX_GPIO_Init(void);
static void MX_I2C1_Init(void);
static void MX_CAN_Init(void);
	/* USER CODE BEGIN 0 */

void HAL_CAN_RxFifo0MsgPendingCallback(CAN_HandleTypeDef *hcan1){
	// Receive CAN message interrupt
	HAL_CAN_GetRxMessage(hcan1, CAN_RX_FIFO0, &rxHeader, canRX);
	HAL_GPIO_TogglePin(GPIOB, GPIO_PIN_3);
	msgRXstatus = 1;
	rxID = rxHeader.StdId;
}

void checkConfig(){

	if (HAL_GPIO_ReadPin(GPIOB, config1_Pin) == 0){
		config++;
	}
	if (HAL_GPIO_ReadPin(GPIOB, config2_Pin) == 0){
		config++;
		config++;

	}
}

void EXTI4_15_IRQHandler(){
	// Push button interrupt
	currentMs = HAL_GetTick();
	 if ((currentMs - lastMs > btnDebounce))
	  {
	    lastMs = currentMs;
	    btnPress=1;
	  }
	 HAL_GPIO_EXTI_IRQHandler(GPIO_PIN_4);
}

void canFilterInit(int hiID, int loID){
  	canfilter.FilterBank = 0;
  	canfilter.FilterMode = CAN_FILTERMODE_IDLIST;
  	canfilter.FilterFIFOAssignment = CAN_RX_FIFO0;
  	canfilter.FilterIdHigh = hiID<<5;
  	canfilter.FilterIdLow = loID<<5;
  	canfilter.FilterMaskIdHigh = 0;
  	canfilter.FilterMaskIdLow = 0;
  	canfilter.FilterScale = CAN_FILTERSCALE_32BIT;
  	canfilter.FilterActivation = ENABLE;
  	canfilter.SlaveStartFilterBank = 1;
  	HAL_CAN_ConfigFilter(&hcan,&canfilter);
}

int byte2Data(int b1, int b2){
	// combine two bytes into a single value
	uint32_t sensorVal = (canRX[b1] << 8)|(canRX[b2]);
	return sensorVal;
}

void scaleData(struct rxData* data){
	float scaled =  (data->val * (data->multi/data->div));
	data->scaled = scaled;

}

void getData(){


	switch(rxID){

	case 512 :
		// counts or enabled status
		warningCount = byte2Data(1,0);
		lastError = byte2Data(3,2);
		revLimit = (canRX[4]) & 1;
		mainRelay = (canRX[4]) & (1<<1);
		fuelPump = (canRX[4]) & (1<<2);
		CEL = (canRX[4]) & (1<<3);
		egoHeater = (canRX[4]) & (1<<4);
		break;


	case 513 :
		rpm.val = byte2Data(1,0);		//RPM
		timing.val = byte2Data(3,2);	//Timing deg
		injDuty.val = byte2Data(5,4);	//Injector Duty %
		injDuty.val = injDuty.val;
		vss.val = canRX[6];				//Vehicle Speed kph
		mph.val = vss.val;
		break;

	case 514 :
		accel.val = byte2Data(1,0);		//Accelerator Position
		tps1.val = byte2Data(3,2);		//TPS 1 Position
		tps2.val = byte2Data(5,4);		//TPS 1 Position
		break;

	case 515 :
		map.val = byte2Data(1,0);			//MAP kPa
		clt.val = canRX[2] - tempOffset; 	//Coolant Temp C
		iat.val = canRX[3] - tempOffset;	//Intake Temp C
		auxT1.val = canRX[4];				//Aux Temp 1 C
		auxT2.val = canRX[5];				//Aux Temp 2 C
		//mcuT.val = canRX[6];				//MCU Temp C
		fuel.val = canRX[7];				//Fuel Level %
		break;

	case 516 :
		afr.val = byte2Data(1,0);		//AFR
		afr.val = afr.val/10;

		oilPress.val = byte2Data(3,2);	//Oil Pressure kPa

		vvtPos.val = byte2Data(5,4);	//VVT Position deg

		battery.val = byte2Data(7,6);	//Battery mV
		break;

	case 517 :
		cylAirMass.val = byte2Data(1,0);	//Cylinder Air Mass mg

		estAir.val = byte2Data(3,2);		//Estimated Air Flow kg/h

		injPW.val = byte2Data(5,4);			//Injector Pulse Width ms

		break;

	}
}

void printText( char* text, int X, int Y){

	// Set cursor and print 11x18 text
	ssd1306_SetCursor(X, Y);
	ssd1306_WriteString(text, Font_11x18, White);

}


void printTextLarge( char* text, int X, int Y){
	// Set cursor and print 16x26 text
	ssd1306_SetCursor(X, Y);
	ssd1306_WriteString(text, Font_16x26, White);

}

void printDataDigitalLarge(struct rxData * data, int X, int Y){

	// Set cursor x/y location and print the selected data
	// If decimal value is 0 it will not be printed
	// This will print the maximum stored value
	ssd1306_SetCursor(X, Y);

	int A = data->scaled;
	int B = (data->scaled - A) * 100;

	if ((data->dec == 0)) {
		snprintf(buff, sizeof(buff), "%d", A);

	}
	else{
		if (B < 10){
			snprintf(buff, sizeof(buff), "%d.0%d", A, B);
		}
		else{
		snprintf(buff, sizeof(buff), "%d.%d", A, B);
		}
	}

	ssd1306_WriteString(buff, Font_16x26, White);

}

void printValue(int data, int X, int Y){
	ssd1306_SetCursor(X, Y);
	snprintf(buff, sizeof(buff), "%d", data);
			ssd1306_WriteString(buff, Font_11x18, White);
}

int getPercent(struct rxData *data){
	// This returns a percentage of the current value vs the set limits for the data

	// Offset current and max values by min, then divide by the max to get the percentage
	int p = ((data->val-(data->min*data->div/data->multi))*100);
	p = p / ((data->max - data->min)*data->div/data->multi);

	// Limit percentage to 0 -> 100
	if (p > 100){
		p = 100;
	}
	if (p < 0){
		p = 0;
	}

	return p;
}

void printStartup(){

#ifdef startupInfo
	ssd1306_Fill(Black);
	printValue(buildDate,5,05);
	printValue(config,100,05);
	printText("CAN 500k",5,25);
	printText("ID 512",5,45);
	ssd1306_UpdateScreen();

#else

	ssd1306_Fill(Black);
	printText("Waiting",5,05);
	ssd1306_UpdateScreen();

#endif

}

void LEDprogress(int l){


	// Set all LED outputs off
				HAL_GPIO_WritePin(GPIOA, LED1_Pin|LED2_Pin|LED3_Pin|LED4_Pin|LED5_Pin|LED6_Pin|LED7_Pin|LED8_Pin|LED9_Pin|LED10_Pin, GPIO_PIN_RESET);


	// Set 1 - 10 LEDs on
	switch(l){

	case 0 :
		 HAL_GPIO_WritePin(GPIOA, LED1_Pin|LED2_Pin|LED3_Pin|LED4_Pin|LED5_Pin|LED6_Pin|LED7_Pin|LED8_Pin|LED9_Pin|LED10_Pin, GPIO_PIN_RESET);
		 break;

	case 1 :
	 	 HAL_GPIO_WritePin(GPIOA, LED1_Pin, GPIO_PIN_SET);
		 break;

	case 2 :
	 	 HAL_GPIO_WritePin(GPIOA, LED1_Pin|LED2_Pin, GPIO_PIN_SET);
		 break;

	case 3 :
		HAL_GPIO_WritePin(GPIOA, LED1_Pin|LED2_Pin|LED3_Pin, GPIO_PIN_SET);
		break;

	case 4 :
		HAL_GPIO_WritePin(GPIOA, LED1_Pin|LED2_Pin|LED3_Pin|LED4_Pin, GPIO_PIN_SET);
		break;

	case 5 :
		HAL_GPIO_WritePin(GPIOA, LED1_Pin|LED2_Pin|LED3_Pin|LED4_Pin|LED5_Pin, GPIO_PIN_SET);
		break;

	case 6 :
		HAL_GPIO_WritePin(GPIOA, LED1_Pin|LED2_Pin|LED3_Pin|LED4_Pin|LED5_Pin|LED6_Pin, GPIO_PIN_SET);
		break;

	case 7 :
		HAL_GPIO_WritePin(GPIOA, LED1_Pin|LED2_Pin|LED3_Pin|LED4_Pin|LED5_Pin|LED6_Pin|LED7_Pin, GPIO_PIN_SET);
		break;

	case 8 :
		HAL_GPIO_WritePin(GPIOA, LED1_Pin|LED2_Pin|LED3_Pin|LED4_Pin|LED5_Pin|LED6_Pin|LED7_Pin|LED8_Pin, GPIO_PIN_SET);
		break;

	case 9 :
	 	 HAL_GPIO_WritePin(GPIOA, LED1_Pin|LED2_Pin|LED3_Pin|LED4_Pin|LED5_Pin|LED6_Pin|LED7_Pin|LED8_Pin|LED9_Pin, GPIO_PIN_SET);
	 	 break;

	case 10 :
		HAL_GPIO_WritePin(GPIOA, LED1_Pin|LED2_Pin|LED3_Pin|LED4_Pin|LED5_Pin|LED6_Pin|LED7_Pin|LED8_Pin|LED9_Pin|LED10_Pin, GPIO_PIN_SET);
	 	break;

	default:
		break;
	}


}

void LEDsingle(int l){

	// Set all LED outputs off
				HAL_GPIO_WritePin(GPIOA, LED1_Pin|LED2_Pin|LED3_Pin|LED4_Pin|LED5_Pin|LED6_Pin|LED7_Pin|LED8_Pin|LED9_Pin|LED10_Pin, GPIO_PIN_RESET);


	// Set single LED 1-10 on
	switch(l){

	case 1:
		 HAL_GPIO_WritePin(GPIOA, LED1_Pin, GPIO_PIN_SET);
				 break;
	case 2:
		 HAL_GPIO_WritePin(GPIOA, LED2_Pin, GPIO_PIN_SET);
				 break;
	case 3:
		 HAL_GPIO_WritePin(GPIOA, LED3_Pin, GPIO_PIN_SET);
				 break;
	case 4:
		 HAL_GPIO_WritePin(GPIOA, LED4_Pin, GPIO_PIN_SET);
				 break;
	case 5:
		 HAL_GPIO_WritePin(GPIOA, LED5_Pin, GPIO_PIN_SET);
				 break;
	case 6:
		 HAL_GPIO_WritePin(GPIOA, LED6_Pin, GPIO_PIN_SET);
				 break;
	case 7:
		 HAL_GPIO_WritePin(GPIOA, LED7_Pin, GPIO_PIN_SET);
				 break;
	case 8:
		 HAL_GPIO_WritePin(GPIOA, LED8_Pin, GPIO_PIN_SET);
				 break;
	case 9:
		 HAL_GPIO_WritePin(GPIOA, LED9_Pin, GPIO_PIN_SET);
				 break;
	case 10:
		 HAL_GPIO_WritePin(GPIOA, LED10_Pin, GPIO_PIN_SET);
				 break;
	default:
		HAL_GPIO_WritePin(GPIOA, LED1_Pin|LED2_Pin|LED3_Pin|LED4_Pin|LED5_Pin|LED6_Pin|LED7_Pin|LED8_Pin|LED9_Pin|LED10_Pin, GPIO_PIN_RESET);
		break;

		}
}

void printGauge(char *t, struct rxData *data2){
//
	currentFilter = data2->ID;
	scaleData(data2);
	p = getPercent(data2);
	printText(t,5,2);
	printDataDigitalLarge(data2,5,30);
	ssd1306_UpdateScreen();

	// Set LEDs
	p = p /10;
	if (config == 1 || config == 3){
		LEDsingle(p);
	}
	else {
		LEDprogress(p);
	}
//
}

void updateGauge(int gaugePrint){

	//Setup CAN filter with address for desired data
	//Print specified data to the display



	ssd1306_Fill(Black);
	switch (gaugePrint){

	case 0 : // AFR
		printGauge("AFR",&afr);
		break;

	case 1 : // Intake Temp C
		printGauge("IAT C",&iat);
		break;

	case 2 : // clt C
		printGauge("CLT C",&clt);
		break;

	case 3 : // map kpa
		printGauge("MAP kPa",&map);
		break;

	case 4 : //Battery
		printGauge("Voltage",&battery);
		break;

	case 5 : //RPM
		printGauge("RPM",&rpm);
		break;

	case 6 : //MPH
		printGauge("Speed MPH",&mph);
		break;

	case 7 : //MPH
		printGauge("Speed KPH",&vss);
		break;


	default : // If no gauge is available move to next

		btnPress=1;
		break;

	}
}


/* USER CODE END 0 */



/**
  * @brief  The application entry point.
  * @retval int
  */

int main(void)
{
  /* MCU Configuration--------------------------------------------------------*/

  /* Reset of all peripherals, Initializes the Flash interface and the Systick. */

	HAL_Init();
  /* Configure the system clock */
  SystemClock_Config();
  /* USER CODE BEGIN SysInit */
  HAL_Delay(startupDelay);
  /* USER CODE END SysInit */

  /* Initialize all configured peripherals */
  MX_GPIO_Init();
  MX_I2C1_Init();
  MX_CAN_Init();
  /* USER CODE BEGIN 2 */

	// Check config jumpers
	checkConfig();

	// Initialize Display
	for (int OLEDInit = 0; OLEDInit<OLEDreinit ; OLEDInit++){
	ssd1306_Init();
	HAL_Delay(10);
	};

#ifdef OLEDstartup
	// Print startup info on OLED
	printStartup();
#endif

#ifdef LEDstartup
	// Startup test for all LEDs
	int cycle = 0;
	while (cycle  < 11){
	LEDsingle(cycle);
	cycle ++;
	HAL_Delay(50);
	}
	HAL_Delay(100);
	LEDprogress(0);
	HAL_Delay(100);
	LEDprogress(10);
	HAL_Delay(500);
	LEDprogress(0);
#endif


// Setup CAN
canFilterInit(filterID[currentFilter], filterID[currentFilter]);
HAL_CAN_Start(&hcan);
HAL_CAN_ActivateNotification(&hcan,CAN_IT_RX_FIFO0_MSG_PENDING);

  /* USER CODE END 2 */

  /* Infinite loop */
  /* USER CODE BEGIN WHILE */

  while (1)
  {
    /* USER CODE END WHILE */

    /* USER CODE BEGIN 3 */


	#ifdef CANtimeout
		  // If no CAN messages are received for the specified wait time alert on OLED
		 if (lastCanMessage > 0 && ((HAL_GetTick() - lastCanMessage) > canWaitTime)){
				ssd1306_Fill(Black);
				printText("Lost",5,5);
				printText("Data",5,20);
				printText("Connection",5,35);
				ssd1306_UpdateScreen();
				LEDprogress(999);
		 	 }
	#endif

	// Get data from received CAN message
	 if (msgRXstatus == 1){
		 getData();
		 msgRXstatus = 0;
		 updateGauge(currentGauge);
		 lastCanMessage = HAL_GetTick();
	 }

	 // Cycle gauges if the button was pressed
	 if (btnPress == 1){

		 // Reset button pressed status
		 btnPress = 0;

		 //Advance to next gauge, cycle back to 1st if at last
		 currentGauge++;
		 if (currentGauge > totalNumGauge){
			 currentGauge = 0;
		 }
		 updateGauge(currentGauge);
		 canFilterInit(filterID[currentFilter], filterID[currentFilter]);
	 }
  }
  /* USER CODE END 3 */
}

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


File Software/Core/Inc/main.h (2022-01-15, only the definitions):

#define MCO_Pin GPIO_PIN_0
#define MCO_GPIO_Port GPIOF
#define LED1_Pin GPIO_PIN_0
#define LED1_GPIO_Port GPIOA
#define LED2_Pin GPIO_PIN_1
#define LED2_GPIO_Port GPIOA
#define LED3_Pin GPIO_PIN_2
#define LED3_GPIO_Port GPIOA
#define LED4_Pin GPIO_PIN_3
#define LED4_GPIO_Port GPIOA
#define LED5_Pin GPIO_PIN_4
#define LED5_GPIO_Port GPIOA
#define LED6_Pin GPIO_PIN_5
#define LED6_GPIO_Port GPIOA
#define LED7_Pin GPIO_PIN_6
#define LED7_GPIO_Port GPIOA
#define LED8_Pin GPIO_PIN_7
#define LED8_GPIO_Port GPIOA
#define config1_Pin GPIO_PIN_0
#define config1_GPIO_Port GPIOB
#define config2_Pin GPIO_PIN_1
#define config2_GPIO_Port GPIOB
#define LED9_Pin GPIO_PIN_8
#define LED9_GPIO_Port GPIOA
#define SWDIO_Pin GPIO_PIN_13
#define SWDIO_GPIO_Port GPIOA
#define SWCLK_Pin GPIO_PIN_14
#define SWCLK_GPIO_Port GPIOA
#define LED10_Pin GPIO_PIN_15
#define LED10_GPIO_Port GPIOA
#define button_Pin GPIO_PIN_4
#define button_GPIO_Port GPIOB
#define button_EXTI_IRQn EXTI4_15_IRQn
#define SPARE_1_Pin GPIO_PIN_5
#define SPARE_1_GPIO_Port GPIOB
#define SPARE_2_Pin GPIO_PIN_6
#define SPARE_2_GPIO_Port GPIOB

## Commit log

2021-10-11 Restructure and add PCB
    Add Schematic, PCB, restructure directories
    [CAN.sch, CAN_Gauge.kicad_pcb, CAN_Gauge.sch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]
2021-10-11 Add PDFs
    Add PDFs of schematic and PCB
2021-10-15 Add config resistors
    Add resistors for adjusting configuration settings
    [CAN_Gauge.kicad_pcb]
2021-10-30 Rev B
    Update STM package, switcher circuit, layout
    [CAN.sch, CAN_Gauge.kicad_pcb, CAN_Gauge.sch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]
2021-10-31 Update components for assembly, generate gerbers
    [CAN.sch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]
2021-12-11 Update board layout
    Fix OLED pads to meet intended design. Move all non UI components to one side of the board for better single sided assembly.
    [CAN.sch, CAN_Gauge.kicad_pcb, LED_Connectors.sch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]
2021-12-28 Add LED ring functionality
    Control the outer LEDs based on the range of the current data. Also add code for Teensy 3.6 used to send test data over CAN.
2022-01-19 Scaling updates
    Some issues with MAP scaling were adjusted.
    [T3.6_rusEFI_CAN_Simulator.ino, main.c]
2022-01-27 OLED Initialization
    Initialize OLED more than once, seems to help with loss of OLED during rapid power cycle. Work in progress...
2022-02-05 Update scaling and variables
    Update scaling, rename variables to make their purpose more clear, adjust LED startup sequence, adjust MAF scaling
2022-02-14 Update scaling, decimal printing, and cleanup
    Adjust scaling calculations to use floats. Decimal printing is configured per data and either always or never shows, two places. Cleaned up some unused code.

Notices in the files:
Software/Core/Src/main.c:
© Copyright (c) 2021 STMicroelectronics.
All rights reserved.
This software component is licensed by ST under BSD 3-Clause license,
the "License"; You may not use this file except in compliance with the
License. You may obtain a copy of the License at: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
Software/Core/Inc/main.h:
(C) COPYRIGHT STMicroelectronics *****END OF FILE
